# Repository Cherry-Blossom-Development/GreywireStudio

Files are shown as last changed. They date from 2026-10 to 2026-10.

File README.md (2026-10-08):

# GreywireStudio

GreywireStudio is a line of guitar effects pedals from Cherry Blossom Development. The first series, **Linework**, is a set of pedals that work on their own or together under a phone-connected control pedal. See `General Concept.docx` for the overall product concept. `Linework Control Specification.docx` defines the rules every Linework pedal follows: the MIDI loop connecting them to Switchyard, the shared message map, presets and firmware updates.

## Tools

All tools are free:

| Tool | Purpose |
|---|---|
| [KiCad](https://www.kicad.org/) | Schematic capture and PCB layout |
| [LTspice](https://www.analog.com/ltspice) | Circuit simulation (gain, clipping, tone response) |

## Layout

```
libraries/
  GreywireStudio.kicad_sym   # Shared KiCad symbols (e.g. 3PDT footswitch)
pedals/
  <pedal-name>/
    README.md   # Design notes, parts list, status
    *Product Document.docx  # Product definition
    kicad/      # KiCad project (schematic + PCB)
    sim/        # LTspice simulations (.asc)
```

## Pedals

| Pedal | Name | Type | Status |
|---|---|---|---|
| [Distortion](pedals/distortion/) | Flashover | Distortion / overdrive | Design |
| [Controller](pedals/controller/) | Switchyard | Control pedal (phone-connected) | Concept |

Product names are working names pending a trademark search.

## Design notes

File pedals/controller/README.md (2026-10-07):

# Controller Pedal (Switchyard)

The Linework series control pedal. A phone (iPhone or Android) plugs into it over USB-C, and two footswitches step up and down through pre-configured settings for all connected pedals. See `Switchyard Product Document.docx`.

## Status

Concept - product definition drafted, no circuit yet.

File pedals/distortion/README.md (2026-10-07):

# Distortion Pedal (Flashover)

The first GreywireStudio pedal: an analog distortion / overdrive in the Linework series, with gain, tone and level controls. It works on its own or controlled by the Switchyard control pedal. See `Flashover Product Document.docx`.

The design files still use the internal name GS1.

## Folders

- `kicad/` - KiCad project (schematic and PCB layout)
- `sim/` - LTspice simulations of the circuit

## Status

Design - circuit not yet started.

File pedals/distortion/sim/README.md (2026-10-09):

# Distortion - LTspice Simulations

## GS1.cir

Simulation of the GS1 schematic's effect-on signal path (footswitch engaged), using the same part names and values as `kicad/GS1/GS1.kicad_sch`.

**To run:** open `GS1.cir` in LTspice (File > Open, set the file type to "Netlists"), then press Run. Click a node or use Plot Settings > Add Traces to view `V(in)` (guitar) and `V(out)` (to the amp). Peak-to-peak levels are in View > SPICE Error Log.

**Settings** are the `.param` lines at the top of the file:

| Param | Meaning |
|---|---|
| `dist` | Distortion knob, 0 (min) to 1 (max) |
| `vol` | Volume knob, 0 to 1 |
| `amp` | Guitar signal level, volts peak (pickups give roughly 0.1-0.3) |
| `freq` | Guitar note frequency, Hz |

By default it steps the Distortion knob through 0, 0.5 and 1 and overlays the three results.

**Models:** LTspice has no LM741 model, so U1 is LTspice's "universal" op amp set to 741 specs. The 1N34A germanium diode model is a common community model, not a manufacturer one.

Generated output (`.raw`, `.log`, `.net`, `.db`, `.wav`) is ignored by git.

## Flashover simulations

The Flashover audio path: the GS1 gain stage scaled for 100k digital pots, switchable Soft (germanium) / Hard (silicon) clipping, a DS-1-style tone control, an output amplifier and a digital-pot Level control. See `Flashover Product Document.docx` one folder up.

| File | Purpose |
|---|---|
| `Flashover_circuit.inc` | The shared circuit. Not run directly; the files below include it |
| `Flashover_listen.cir` | Runs 2 seconds and writes `Flashover_out.wav` at the knob settings in the file |
| `Flashover_compare.cir` | Soft vs Hard at two Gain settings: output level, and checks that every digital pot terminal stays within 0-9V |
| `Flashover_tone.cir` | 20 Hz-20 kHz response at three Tone settings, 10k vs 20k Tone pot, and min/max Gain |

**Settings** (`.param` lines at the top of each run file): `dist`, `tone`, `level` (knobs, 0 to 1), `hard` (0 = Soft, 1 = Hard), `Rt` (Tone pot value), `Rw` (digital pot wiper resistance), `amp`, `freq`.

**Design changes from GS1, and why:**

- Digital pots only accept signals between 0V and 9V, so everything after the gain stage is centered on the 4.5V reference (VB) instead of ground. VB is buffered by an op-amp (U3) because the tone network and Level pot now return to it.
- Gain stage scaled by 10 for a 100k digital pot: R5 100k, R4 330 (instead of 470, to allow for the pot's wiper resistance: about 150 ohms at 9V according to the MCP45HV51 datasheet), C3 470n. Gain at 1 kHz: about 1.8x to 170x, the same as GS1.
- Output amplifier (U2) has a gain of 4 (+12 dB) to make up the tone network's loss, so the pedal can play louder than the bypassed guitar.

**Results (October 2026):**

- All digital pot terminals stay between about 3.4V and 5.5V, inside the 0-9V limit.
- Hard is about 8.5 dB louder than Soft at full Gain (7.7 dB at half Gain). Multiplying Level by 0.376 in Hard mode matches the loudness to within 0.1 dB, so the firmware can compensate automatically.
- A 10k Tone pot (available as a 9V digital pot) gives tone curves within about 3 dB of the DS-1's 20k, so 10k is used.
- At full Level and Gain, output is about +6 dB (Soft) and +14.5 dB (Hard) above the input guitar signal.

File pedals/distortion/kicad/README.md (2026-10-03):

# Distortion - KiCad Project

Create the KiCad project in this folder (File > New Project in KiCad).

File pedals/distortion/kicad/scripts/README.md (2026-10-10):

# Flashover generator scripts

These Python scripts generate the Flashover KiCad projects (`../Flashover` and `../Flashover_Controls`).

**Once anyone routes a board by hand in KiCad, the KiCad files become the master copy.** After that,
don't run `make_boards.sh`: it overwrites the `.kicad_pcb` files. The schematic generator
(`gen_flashover.py`) overwrites the schematics in the same way.

| Script | What it does | Run with |
|---|---|---|
| `gen_flashover.py` | Writes both schematics and their project files. Uses `kigen.py` and `kisym.py` | any Python 3 |
| `rules.py` | Design rules and net classes, written into the `.kicad_pro` files | (imported) |
| `netlists.sh` | Exports both netlists to `build/`, for the placement script | bash |
| `gen_pcb.py` | Places every part on both boards, in 1590BB pedal coordinates, and adds the board outline and copper planes | KiCad's Python |
| `fanout.py <project>` | Adds a short track and a via from each surface-mount pad down to its inner plane (GND on both boards, +5V on the control board) | KiCad's Python |
| `route.sh <project> [passes]` | Autoroutes with Freerouting (`route.py` and `dsnfix.py` handle the round trip), then adds ground pours | bash |
| `make_boards.sh [max passes]` | All of the board steps above, for both boards, followed by `drc.sh` | bash |
| `drc.sh` | Runs the design rule check, with schematic parity, on both boards and prints a summary | bash |
| `render.sh` | Renders both boards to `build/*_pcb.png` | bash |

- **Paths:** set in `paths.py` and `env.sh`. The KiCad 10 install paths are in `env.sh`, `gen_pcb.py` and `kisym.py`.
- **`build/`:** not committed. It holds netlists, router files and logs.
- **Freerouting:** download version 2.1.x (it runs on Java 21) from
  <https://github.com/freerouting/freerouting/releases> and save it as `build/freerouting.jar`.
- **Router quirks:**
  - Run headless, Freerouting ignores every pass limit tried (`-mp`, `--router.max_passes`, the settings file). It stops by itself after about 1,000 passes; `route.sh` also stops it after 90 minutes, and a stopped run saves nothing.
  - It can't connect pads at angles other than multiples of 90°, so the ring LEDs and U10 are placed square.
- **KiCad's Python quirk:** `pcbnew.SaveBoard` resets the project's design rules. Every script that
  saves a board calls `rules.apply_file` afterwards to put them back.

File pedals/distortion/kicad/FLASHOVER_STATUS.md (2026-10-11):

# Flashover circuit boards: where we are (updated 2026-10-10)

## In short

The schematic is finished and the parts are placed on two circuit boards. Wiring the boards together
("routing") is partly done: the control board is nearly finished, but the main board still needs
substantial work. Nothing is ready to order yet.

## What exists

Two KiCad projects, one per board:

| Folder | Board | What's on it |
|---|---|---|
| `Flashover/` | Main board | Audio circuit, microcontroller, digital pots, MIDI, bypass relay, and all five jacks along the top edge |
| `Flashover_Controls/` | Control board | The three knobs with their LED rings, the LED driver, the Soft/Hard button and the four panel LEDs |

- **Enclosure:** Hammond 1590BB, with the jacks mounted along the top edge.
- **Stacking:** the control board sits just under the top panel and plugs into the main board below it
  through a 20-pin connector (J8 on the control board into J7 on the main board).
- **Spacers:** two M3 screw holes on each board, in matching positions.
- **Panel layout (looking down at the pedal):**
  - Gain and Level knobs side by side at the top, with Tone below and centred.
  - Soft/Hard button at the lower left, with the Soft and Hard LEDs just above it.
  - On LED just above the footswitch; Link LED under the Level knob.
- **Schematic check:** passes with no errors on both projects.
- **Board check:** both boards match their schematics exactly.

## Where the routing stands

Both boards are 4-layer. The two inner layers are copper "planes" for ground (and +5V on the control
board), which keeps the audio quiet and cuts down the wiring.

| Board | Connections still missing | Wiring errors (shorts or too-close tracks) |
|---|---|---|
| Control board | **0 — fully routed** (last 7 by hand, 2026-10-10) | 0 |
| Main board | 50 | 0 |

- **Control board:** finished. The last 7 connections, all around the LED driver chip (U10), were
  routed by hand. Only cosmetic silkscreen (label) warnings remain, to be tidied before ordering.
  - L7 takes a long way round, past the right-hand knob and back. It works; tidy it later if wanted.
- **Main board:** the automatic router (Freerouting) gets most of it, but leaves gaps, mostly around
  the microcontroller's very fine pins.
- **Why route the main board by hand:** even a fully auto-routed main board would route the audio path
  poorly. My recommendation is to route it by hand in KiCad, starting with the audio path:
  input jack → gain → clipping → tone → output.

## Things to check against real parts before ordering

- **Jack spacing:** the five jacks along the top edge are very tight, with about 1 mm between bodies.
  A smaller 1/4" jack such as the Lumberg KLBM 3 would free about 10 mm (it needs a custom footprint).
- **Enclosure measurements:** I assumed walls about 3 mm thick and corner screw posts about 6.5 mm
  across. Both need checking against Hammond's 1590BB drawing.
- **Board stacking height:** the boards are about 11 mm apart, with the control board about 8 mm below
  the panel. This depends on the actual encoder and button heights.
- **Ring LEDs:** they sit below the panel, so each knob needs 11 small panel holes, or light pipes.
- **Encoders:** they use the Alps EC11E footprint. Confirm it matches the Bourns PEC11R drawing.
- **Audio capacitors:** C1–C5, C8, C9 and C12 must be C0G or film, not X7R.

## Done on 2026-10-10

- **Generator scripts saved** in `scripts/`, with a README explaining how to run them. Run from
  there, they reproduce the committed schematics exactly.
  - Once routing by hand starts, the KiCad files become the master copy. Don't re-run
    `make_boards.sh` after that: it overwrites the boards.
- **Product document updated** for the two-board design: a new "Circuit boards" section, and the
  sheet table now shows which board each sheet is on.
- **Tried to help the autorouter:** I turned the main board's In2 layer into a 3.3V plane, because
  half of the missing connections were 3.3V.
  - It made things worse, 70 missing connections instead of 50, including parts of the audio path.
    Losing In2 as a routing layer cost more than the plane saved.
  - I reverted it. The boards are as committed on 2026-10-09.
- **Conclusion:** the automatic router has gone as far as it usefully can on the main board.

## Next

**Hand-route the main board** in KiCad, together, the same way as the control board: one connection
at a time, with a check after each save. Start with the audio path:
input jack → gain → clipping → tone → output.

How to route by hand in KiCad (what worked on the control board):
- Use the **Design Rules Checker → Unconnected Items** list to find each gap.
- Set the grid to **0.1 mm** so the cursor can reach the fine-pitch pads.
- **Page Up** selects the top layer (F.Cu, red); **Page Down** the bottom (B.Cu, blue).
- Drawing a track:
  - **X**, then click the start, to begin.
  - Click to fix a corner.
  - **V**, then click, drops a via and changes layer.
  - **Esc** twice to stop.
- Surface-mount pads are only on the top layer, so a track arriving on the bottom needs a via
  just before the pad.
- If clicking opens the footprint chooser, a tool is on: press **Esc** until the arrow is selected.

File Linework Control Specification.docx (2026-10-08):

# Linework Control Specification

Shared rules for every pedal in the Greywire Linework series

Item | Detail
Version | 0.1 (draft)
Status | First proposal, to be refined as each pedal is designed
Applies to | Switchyard and every Linework effect pedal (Flashover is the first)
Related documents | General Concept.docx; Switchyard Product Document.docx; Flashover Product Document.docx

# Purpose

Every Linework pedal has to work with Switchyard, the app and every other Linework pedal, including pedals we haven’t designed yet. This document sets the rules they all follow: how they connect, how they’re controlled, what messages they understand, and how they’re updated.

The goal is that each new pedal can be designed on its own as long as it follows this specification. We don’t have to design every pedal before building the first one. Because every pedal can receive firmware updates, the specification can also be improved later and existing pedals updated to match.

# Design rules for every pedal

- Linking is always included. There are no unlinked versions of Linework pedals.
- No control holds a position that could disagree with a remote change. Knobs are endless (rotary encoders) with LED rings showing the real value. Switches are push buttons or momentary footswitches, with LEDs showing the real state.
- Settings survive power off. A pedal starts up exactly as it was left.
- Fail-safe bypass. The on/off switching uses a relay that connects input straight to output when the pedal has no power, so a dead pedal still passes the guitar signal.
- Presets. Every pedal stores 128 presets that can be recalled with a MIDI program change.
- Firmware updates through Switchyard, with a protected spare copy so a failed update can’t leave the pedal unusable.
- Power: standard 9V DC, 2.1 mm barrel, center negative. Each pedal lists its current draw.
- No batteries. Every pedal runs from a power supply cable; there is no battery compartment.

# Connections

## The MIDI loop

All Linework pedals connect to Switchyard in a single loop using standard MIDI over 3.5 mm TRS cables (“Type A” wiring). Every pedal has one MIDI in and one MIDI out jack.

- Switchyard MIDI out → pedal 1 MIDI in
- Pedal 1 MIDI out → pedal 2 MIDI in, and so on for each pedal
- Last pedal MIDI out → Switchyard MIDI in

Each pedal passes on everything it receives and adds its own messages (such as a knob turned by hand, or a reply to a question from Switchyard). This is called merging. It means:

- Switchyard needs only one output and one input, however many pedals are connected.
- Switchyard hears from every pedal, so the app always knows the current settings, which pedals are connected, and in what order.
- If a message doesn’t come back around the loop, Switchyard knows the loop is broken and the app can show where.

## Limits

- Up to 16 pedals, one per MIDI channel.
- Each pedal adds a very small delay as it passes messages on (well under 1 ms per message). A typical board of 6–8 pedals is no problem.
- MIDI cables carry control messages only, never audio or power.

## If a pedal loses power

A pedal with no power stops passing messages on. Because pedals have no batteries, this only happens if a power cable is knocked out or a supply fails, so no extra hardware is added for it. Instead:

- The sound keeps working. The unpowered pedal’s bypass relay passes the guitar signal straight through, so only that one effect drops out.
- Pedals before the break still receive Switchyard’s messages; only the pedals after it lose contact.
- Switchyard detects the break because its messages stop coming back around the loop, and the app shows which pedal to check.

# Setting up: identifying pedals and assigning channels

Channels are assigned automatically. The player only has to cable the loop.

- 1. Count: Switchyard sends a “position” message carrying the number 0 around the loop. Each pedal adds one, remembers the result as its position, and passes the new number on. The number that arrives back at Switchyard is the total number of pedals.
- 2. Identify: Switchyard sends the standard MIDI “identity request” around the loop. Each pedal replies with its model, firmware version, specification version, its position, and a unique serial number built into its microcontroller. From the positions, the app knows the order the pedals are cabled in.
- 3. Assign: Switchyard sends each pedal, addressed by serial number, the channel it should use. The pedal remembers its channel.
- 4. Confirm: the app shows the list of pedals in board order with their channels.

Manual fallback: every pedal has a setup mode, entered by holding its footswitch while plugging in power, where the channel can be chosen by hand and shown on the pedal’s LEDs. The exact controls depend on the pedal.

# Message map

## Control change messages

All pedals use the same control change numbers for the same kinds of controls, so Switchyard and the app can handle any pedal the same way.

Control change | Use | Values
20–27 | Knobs 1–8, in panel order (left to right, then top to bottom) | 0–127, fully down to fully up
52–59 | Optional fine adjustment for knobs 1–8 (standard MIDI pairing, for 16,384 steps instead of 128) | 0–127
80 | Effect on/off | 0–63 off, 64–127 on
81–87 | Mode switches 1–7 (such as Flashover’s Soft/Hard) | The option number: 0, 1, 2 and so on
Others | Reserved for future use

When a setting is changed by hand on a pedal, the pedal sends the same message out on its own channel, so Switchyard and the app stay in sync.

## Program change messages

- Program change 0–127 recalls preset 1–128 on that pedal’s channel.
- When a preset is recalled, the pedal sends its new settings out as control change messages so the app sees the result.

## System messages

Messages that aren’t about a pedal’s sound use MIDI “system exclusive” messages, which carry our own manufacturer ID. Proposed messages:

Message | Direction | Purpose
Position count | Switchyard → pedals → Switchyard | Each pedal learns its place in the loop; Switchyard learns how many pedals there are
Identity request / reply | Switchyard → pedals → Switchyard | Find out which pedals are connected (uses the standard MIDI identity request)
Assign channel | Switchyard → pedal | Set a pedal’s channel, addressed by its serial number
Report settings | Both ways | Ask a pedal for all its current settings; the pedal replies with them
Store preset | Switchyard → pedal | Write a preset slot, either with given values or with the pedal’s current settings
Read preset | Both ways | Read back a preset slot so the app can check it matches its copy
Firmware update | Both ways | Start, send data, verify and finish a firmware update (see below)

The detailed byte layout of each message will be written once the first prototype is working.

Manufacturer ID: MIDI reserves a temporary ID (7D) for development and non-commercial use, which we can use while prototyping. Before selling, we need our own ID from the MIDI Association, which has a small annual fee.

# Presets

- Every pedal stores 128 presets in its own memory, recalled by program change 0–127.
- Each pedal’s product document lists what a preset holds. For Flashover it’s Gain, Tone, Level, clipping mode and on/off.
- The app holds the master copy of every preset and writes them to the pedals through Switchyard. It can read them back to check they match.
- Proposal for setlists: when the app sends a setlist to Switchyard, it stores the settings each song part needs as presets in each pedal. Stepping to the next part then needs only one program change message per pedal. Switchyard can still send individual control change messages for live adjustments.

# Firmware updates

- Route: the app downloads firmware from the Greywire server, sends it to Switchyard over USB, and Switchyard sends it around the MIDI loop addressed to one pedal by serial number. The pedal confirms each part and reports when it’s finished.
- Protected: each pedal keeps two copies of its firmware. Updates go into the spare copy and are checked before the pedal switches over. A failed or interrupted update leaves the old version running.
- Recovery mode: each pedal has a button combination at power-up that starts a minimal recovery program waiting for a new update. Each product document lists its combination.
- During an update the pedal stays in bypass, so the guitar signal still passes.
- Speed: MIDI moves about 3 KB per second, so a typical update of 100–200 KB takes one to two minutes per pedal.
- Switchyard itself is updated directly over USB from the app.

# Timing

- A control change message takes about 1 ms to send.
- A preset change (one program change per pedal) takes about 1 ms per pedal, so a board of 8 pedals changes in under 10 ms.
- Sending every setting individually takes about 5 ms per pedal for a pedal like Flashover, so presets are the faster way to switch songs.

# Versioning

- Every pedal reports which version of this specification it follows, in its identity reply.
- New versions of the specification should only add things, never change the meaning of existing messages, so older pedals keep working.
- Pedals can be updated to newer versions with a firmware update.

# Open questions

- Do any pedals need more than 8 knobs or 7 mode switches?
- Is the fine-adjustment range (control change 52–59) needed for any pedal, or is 128 steps enough?
- Confirm the setlist proposal: presets in the pedals, recalled by program change.
- Should Switchyard offer a second loop for very large boards?

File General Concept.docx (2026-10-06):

What are we building?

Original idea

1) a multi-effects pedal
2) which connects to the internet
3) Therefore, we need a website

or maybe..

1) a small network of single effects pedals
2) which connect to each other
3) and maybe a master control pedal
4) also connecting to the internet
5) necessitating a website.

What features could we have

1) Pedal does what a pedal does (same as any other pedal)
2) pedal allows for remote control (either wirelessly or via a cable of some sort)
3) The remote control can adjust any pedal setting
4) The remote control is centralized and sequenced into easily changeable modes to accommodate any song. pre-set in order to play your songs, all controllable by a single tap floor-based device (a pedal)
5) The remote control can also integrate with external sound sensing devices (aka cellphones), which can determine overall band levels and adjust them live during a live, on-location performance
6) Somehow, the pedal also allows you to access a limited social network of other people who also have one of the devices (perhaps you need a specific MAC address or something to validate, not sure how this works actually)

Questions:

Question 1: If the pedals all do the same basic thing that other pedals do, why would anyone purchase them (especially if they cost more)

Answer: It’s all the other features you get from the remote-control stuff to the social network. This is added value

Question 2: What if the external control is annoying? Like, what if it turns your sound level down to the point where you can’t hear yourself?

Answer: We have a special monitoring device that goes along with the pedal, a little speaker that sits on your pedal board and can be adjusted independently

Question 3: Why would I want to use this social network?

A) The social network connects you to other musicians. This could be good, you could start a band or something
B) The social network also has built-in mixing and recording tools. The pedal can upload recordings directly to the network, which can be reviewed by others

Question 4: What about drummers?

Answer: Drummers suck… but for real though, we could also make drum tools, or also we could simply have a subscription model for people who want to be part of the network but don’t have a device available (like Saxophone players, fuck those guys)

Question 5: So, does the pedal also record you?

Answer: Uh, yeah, maybe? I just typed that, so I guess we should look into it

# Connectivity: How Does the Pedal Reach the Internet?

Both ideas (Wi-Fi through the phone, or Bluetooth to the phone) work, and we don’t have to pick one. The usual chip for this, the ESP32, has Wi-Fi and Bluetooth built in and costs a few dollars. The bigger cost decisions are elsewhere: certification, the phone app, and how the pedals talk to each other.

## Option 1: Wi-Fi through the phone’s hotspot

Doable. The command pedal joins the phone’s hotspot like a laptop would. Some catches:

- Users have to turn on their hotspot every time. On iPhone it’s fiddly, and some phone plans charge for it or cap it.
- The same Wi-Fi radio can join home or venue Wi-Fi directly, so the hotspot should be a fallback, not the main path.
- Big advantage: we might not need a phone app at all. The pedal can serve a setup page, then talk straight to the website. The Breakroom backend already does this kind of thing.
- Wi-Fi is fast enough to upload recordings.

## Option 2: Bluetooth (BLE) to a phone app

Doable, and it’s how most commercial “smart” pedals and amps work (Boss, Line 6, Positive Grid Spark). The pedal talks to an app, and the app relays to the internet.

- It needs a native phone app. iPhone browsers can’t talk to Bluetooth devices, so that means an Android app (Kotlin) plus an iOS app.
- Connecting is easy for users: pair once and it reconnects automatically.
- Lag is low, around 10–30 ms, which is fine for switching presets.
- It’s slow for big files. A 3-minute recording is about 15–30 MB, and BLE would take minutes to move it.
- This concept needs apps anyway. The musician needs an app to control the pedal, and the band-level feature needs an app for the separate person who measures the band’s mix (see Band-Level Monitoring at the end of this document). That tilts things toward Bluetooth.

## Recommendation: both, on one chip

Put an ESP32-S3 in the command pedal only:

- Bluetooth to the phone app for control and presets, and to receive level adjustments from the band-level feature
- Wi-Fi for uploading recordings, firmware updates and the social network when a network is available

Two rules:

- Never send a footswitch press over the internet. Song-mode changes have to work locally, in a basement with no signal.
- Connect the effect pedals to the command pedal with a cable, not wirelessly. A crowded stage is full of 2.4 GHz interference, and a missed preset change mid-song is a dealbreaker. MIDI over a TRS cable is the industry standard and cheap. A cable also keeps radio noise out of each pedal’s analog audio.

## Other options

Option | Verdict
USB-C to phone or computer | Worth adding. It’s cheap, very reliable and great for recording. Could be a second path rather than the main one.
ESP-NOW (ESP32-to-ESP32 wireless, no router) | Works for pedal-to-pedal links, but has the same stage-reliability worry as above.
Cellular (LTE-M or 4G module) | Works anywhere, but costs $10–30 per unit, plus a $2–10/month data plan and expensive carrier certification. Not worth it at this stage.
Ethernet | Nobody runs network cable to a pedalboard.

## What this means for the GS1 circuit

- Remote control of knobs: GS1 uses ordinary mechanical knobs, which a chip can’t turn. We’d need digital potentiometers that run on the full 9V (e.g. Microchip MCP41HVxx, about $1.50–2.50 each). Another route is doing the effect digitally in software.
- Recording: the ESP32’s built-in audio input is too poor for this. We’d need an audio converter chip (about $2–5) and an SD card slot (about $1).

## Rough costs

Parts per pedal (at small production runs)

Item | Cost
ESP32-S3 module (Wi-Fi and Bluetooth, pre-certified) | $3–6
Power converter from 9V to 3.3V* | $1–3
MIDI jacks and parts for the cable link | $1–2
Small chip in each effect pedal to receive commands | $1–3
9V digital pots, per knob | $1.50–2.50
Audio converter and SD slot (if recording) | $3–6
Extra cost, command pedal | about $10–20
Extra cost, each effect pedal | about $3–8

*Wi-Fi draws bursts of up to about 350 mA. A simple regulator from 9V would get too hot, so a more efficient switching converter is needed.

Retail price usually ends up about 3–4× the parts cost.

One-time and ongoing costs

Item | Cost
Prototyping boards (ESP32-S3 DevKit is about $15) | $50–150
FCC testing (US), using a pre-certified module | about $2k–5k
CE/RED testing (only if selling in the EU) | about $3k–10k
Bluetooth SIG listing fee (required to sell anything with Bluetooth) | about $5k–10k; check the current price
Apple developer account | $99 per year
Google Play account | $25 once
Server | Already running on EC2

The Wi-Fi Alliance logo program is optional. The Bluetooth fee and FCC testing are the big unavoidable costs, and they’re one-time costs per product. Using a pre-certified radio module, rather than designing our own radio, is what keeps FCC testing in the low thousands instead of tens of thousands. The certification prices are estimates, so get quotes before budgeting around them.

## Next step

Finish GS1 as a plain analog pedal. Separately, buy an ESP32-S3 dev board (about $15) and a 9V digital pot, and prototype changing GS1’s Distortion knob from a phone over Bluetooth. That one experiment tests the core idea for about $20.

# Certification Without Wi-Fi or Bluetooth

Mostly not needed, at least in the US, as long as the pedals stay fully analog.

## United States (FCC)

A fully analog pedal like GS1 needs no FCC testing or paperwork. FCC rules cover devices that transmit radio on purpose, like Wi-Fi and Bluetooth. They also cover “digital devices,” meaning anything with a clock signal running above 9 kHz. An op-amp, diodes and knobs are neither, which is why most small builders who make analog pedals sell them in the US without testing.

We still can’t cause harmful interference, but a properly built analog pedal won’t.

This changes as soon as we add a chip with a clock. Examples are a microcontroller for preset switching, relay bypass or tap tempo, or a digital delay chip like the PT2399. The pedal then counts as a Class B digital device. That means a self-declaration, but in practice it means paying a lab to test emissions, typically about $1k–3k per product. It’s still much cheaper than the wireless route, and there’s no FCC filing fee or ID number.

## Fees that go away entirely

- Bluetooth SIG fee: only applies to Bluetooth products.
- Apple and Google developer accounts: no app needed.

## Selling in Europe or the UK

These rules apply even to analog pedals:

- CE marking (UKCA in the UK). The EMC rules cover any electronic device. Self-declaration is allowed without a mandatory lab test, but it requires a technical file. Many small makers pay for a test anyway to be safe, about $1k–3k.
- RoHS: parts and solder must be lead-free. That’s easy if we plan for it from the start.
- WEEE registration: a recycling registration in each country we sell to. It’s small but annoying paperwork, especially in Germany.

Selling only in the US to start avoids all of this.

## Smaller things that still apply

- Power supply: don’t make our own. If one goes in the box, buy one that’s already safety-certified (UL/ETL). Most pedal makers don’t include one at all, and players already own one.
- California Prop 65: standard pedal jacks are made of brass that contains a little lead. Many pedal makers add a Prop 65 warning label. It costs nothing, but it’s worth knowing about.
- Product liability insurance: not required, but common once sales get going. Typically a few hundred to a couple thousand dollars a year for a small business.

So plain analog pedals sold in the US have essentially no certification cost. That makes GS1 a good first product to sell while the connected version is worked out.

This is a general picture, not legal advice. Before selling in Europe, a compliance lab will give a free quote and confirm exactly what applies.

# Alternative: Plug the Pedal Into the Phone (USB-C)

Instead of building Wi-Fi or Bluetooth into the pedal, it could plug into the player’s phone with a USB-C cable and use the phone’s connection. This works, and it’s cheaper. Most of the savings are one-time fees, though; the per-pedal savings are only a few dollars. It’s also the better option for recording and the worse one on stage.

## How it would work

The pedal gets a USB-C port and a small microcontroller. It plugs into the phone, and a phone app relays everything to the internet.

The key design trick: make the pedal a standard USB audio and MIDI device, the same kind as the plug-in guitar interfaces sold for phones. iPhones (USB-C models, iPhone 15 and later) and Android phones support these with no special drivers. Control messages go over MIDI, and recordings stream as full-quality audio.

Older Lightning iPhones would need Apple’s $29–39 camera adapter. Making a pedal that talks to iPhones any other way requires Apple’s MFi licensing program, which is slow and restrictive, so stick to the standard device types.

## What it saves

Cost | Wireless (ESP32) | USB to phone
Bluetooth SIG fee | $5k–10k | $0
FCC testing | $2k–5k (radio product) | $1k–3k (self-declared digital-device test)
USB vendor ID | — | $0 with a free product ID from the chip maker (Raspberry Pi and others offer these); $6k to buy our own
App development (iOS + Android) | Needed | Still needed
Parts per pedal (control only) | about $10–20 | about $3–6
Parts per pedal (with recording) | plus audio chip and SD card | about $6–15; no SD card needed, the phone stores it

The microcontroller can be very cheap, e.g. a Raspberry Pi RP2040 at about $1, which has USB built in. We also skip the switching power converter, because there’s no Wi-Fi drawing big bursts of current. A Class B digital device still needs that FCC test, though, so we save on the Bluetooth fee but not all certification.

Rough total savings: about $5k–12k up front and about $5–10 per pedal.

## The trade-offs

Better:

- Recording is much better. Full-quality audio streams straight into the phone app, with no slow Bluetooth transfers and no SD card. It also works with a laptop recording program, which is a nice extra.
- No radio interference anywhere near the analog audio.
- Simpler firmware and fewer connection problems.

Worse:

- The phone has to sit on the pedalboard, plugged in, for the whole gig. Cables get kicked, notifications pop up, and the phone’s only port is in use, so it can’t charge without a hub. That’s awkward for live use.
- Hum risk: the phone (especially while charging) plus the amp can create a ground loop. We may need a USB isolator chip, about $5–8 per pedal, which eats into the savings.
- The phone can’t really power the pedal, so it still needs its normal 9V supply.

## How it fits the concept

A sensible staged plan:

- Version 1: USB only. The pedal works standalone on stage, with presets and song modes stored in the pedal itself. Players plug it into a phone or computer at home to edit presets, record, upload to the social network and update firmware. This is the cheapest way to launch the internet-connected idea.
- Version 2: add wireless once sales justify the Bluetooth and certification costs, so players can control the pedal without their phone plugged into the pedalboard. The band-level feature doesn’t need this; it works through the musician’s phone in version 1.

A first prototype costs about the same as before: an RP2040 board (about $5) and a 9V digital pot, controlled from an Android phone over USB MIDI.

# Fully Integrated Mobile Device

The original plan was analog effect circuits in each pedal, plus a small computer (like an Arduino) in the pedal to receive commands and change settings such as volume. With the pedal plugged into a phone, the phone can take over much of that work, and even produce some of the effects itself in software.

The chosen direction is a hybrid. Effects where delay would be a problem stay as real analog circuits built into the pedal. Effects that are naturally digital run as software in the phone app. This section explains how that works, why it solves the latency problem, and what it costs.

## The short answer

- Analog in the pedal: drive effects (distortion, overdrive, fuzz, boost), dynamics (compression, noise gate), filters and wah, and modulation that changes the whole signal (phaser, flanger, tremolo, vibrato). These need an instant response, and they’re traditionally analog anyway.
- Digital in the phone: reverb, delay, chorus and pitch shifting, plus tools like a looper and tuner. These are traditionally digital, and they tolerate a small delay if the design is done right.
- The trick that makes it work: the clean (“dry”) signal never goes through the phone. The phone only adds the effect sound (the “wet” signal) on top, so the phone’s delay doesn’t affect the feel of playing.
- The pedal still needs a small computer. Since the analog effects are in the pedal and the phone needs to change their settings, the pedal needs a small, cheap microcontroller (about $1–4) to receive commands and set the knobs.
- Certification: one product with a USB chip needs one FCC self-declared test (about $1k–3k). Building several analog effects into one box instead of separate pedals means one test, not several.
- Bonus: if the phone dies on stage, the analog effects keep working. Only the reverb and delay drop out.

## Why a phone can’t turn a knob directly

A phone’s USB-C port carries only digital data, plus 5V power. When the phone and pedal are connected, the phone is in charge (the USB “host”) and the pedal is a “device.” The phone sends and requests small packets of numbers, and something on the pedal has to receive those packets and turn them into an action. The phone can’t put an arbitrary analog voltage on a pin to move a volume setting.

One possible shortcut is a dead end. Some Android phones support passing plain analog audio through the USB-C port (the mode used by cheap USB-C headphone dongles). iPhones don’t, and many Android phones don’t either, so we can’t rely on it.

Since the hybrid design keeps analog circuits in the pedal, something in the pedal has to receive the phone’s commands and adjust those circuits. That’s the microcontroller’s job.

## Options considered

| A. Phone does everything | B. Analog pedal, no-code USB chip | C. Analog pedal, small microcontroller | D. Hybrid (chosen)
What’s in the pedal | Guitar in/out circuits, USB audio chip, footswitches | Analog effects, digital pots, a USB bridge chip | Analog effects, digital pots, a microcontroller | Analog effects, digital pots, a microcontroller, a USB audio path to the phone
Where the sound is made | All in the phone | All in the pedal | All in the pedal | Drive, dynamics, filters, wah and whole-signal modulation in the pedal; reverb, delay, chorus, pitch, looper and tuner in the phone
Works with iPhone? | Yes | No; iPhone apps can’t talk to custom USB devices | Yes | Yes
Latency risk | High, every note goes through the phone | None | None | Low; only the wet signal goes through the phone
If the phone fails | Silence (needs a bypass relay) | Pedal keeps working | Pedal keeps working | Analog effects keep working; digital effects drop out

Option A had the cheapest hardware, but every note would pass through the phone, and Android phones vary too much in speed for that to be reliable. Option D keeps the parts of A that work well and avoids its biggest risk.

## Which effects go where

Our general split matches how the industry already works. The rule of thumb: if an effect needs an instant response, or it changes the whole signal so there’s no dry signal to keep instant, it goes in the pedal. If it adds something on top of the dry signal, it can go in the phone.

The Status column shows which placements we’ve decided and which are proposed and still to be reviewed one at a time. This is the full catalog. Which effects go into the first product is a separate decision; not every effect fits in one pedal.

Analog, in the pedal

Effect | Why | Status
Compression | Has to react instantly to how hard the string is hit | Decided
Noise gate | Must cut hum and hiss instantly between notes. A simple analog circuit | Proposed
Clean boost | Just a gain stage with a handful of parts | Proposed
Overdrive, distortion, fuzz | The core of the player’s tone; GS1 becomes the first of these | Decided
Octave fuzz, analog octave down | Classic analog circuits that follow the playing instantly. They complement the phone’s pitch shifting rather than replacing it | Proposed
Wah | The player sweeps it with their foot in real time, so any delay would be felt immediately | Decided
Volume pedal | Also controlled by the foot in real time; can share the expression pedal jack with the wah | Proposed
Filters (EQ, envelope filter / auto-wah) | Cheap and classic as analog circuits; feel matters | Decided
Phaser | Blends the signal with a phase-shifted copy of itself, which needs perfect timing. Also a cheap, classic analog circuit | Decided
Uni-Vibe style | A 1960s cousin of the phaser; same reasons | Proposed
Flanger | Needs very short delays (about 1–10 ms), shorter than the phone can manage. Analog flangers use a “bucket brigade” delay chip | Decided
Vibrato | Bends the pitch of the whole signal, so there’s no dry signal to keep instant. Uses the same bucket brigade chip as the flanger | Decided
Tremolo | Changes the volume of the whole signal. Simple and cheap as an analog circuit | Decided
Ring modulator | Changes the whole signal; a classic analog circuit | Proposed

Digital, in the phone

Effect | Why | Status
Reverb | Reverb naturally starts a little after the note, so a small delay is inaudible | Decided
Delay / echo | The app subtracts the phone’s delay from the echo time, so echoes land exactly on time | Decided
Chorus | Mixes in a copy delayed by roughly 10–25 ms anyway, so it works if the phone’s delay is shorter than that. Fine on iPhone; slower Android phones may struggle. Could move to analog later using the flanger’s delay chip | Proposed
Harmonizer (adds a pitched note alongside the original) | The original note stays on the instant dry path | Decided
Whammy / polyphonic pitch shift (replaces the original note) | There’s no dry signal to hide behind, so the delay is audible on slow phones. Best treated as an iPhone or fast-phone feature | Decided
Looper | Records and plays back loops. The app knows the phone’s delay, so it can line loops up exactly, and the phone has plenty of storage | Proposed
Tuner | Only needs to listen, so delay doesn’t matter. The pedal mutes its output while tuning | Proposed
Amp and speaker cabinet simulation | Changes the whole signal, so the phone’s delay matters when playing live. Most useful for headphone practice and recording straight into the phone | Proposed

## How the signal flows

1. Guitar input: a buffer circuit prepares the guitar signal.

2. Analog chain, in the usual order: compressor, then wah and filters, then octave and drive (fuzz, overdrive, distortion, boost) with the noise gate after them, then modulation (phaser, Uni-Vibe, flanger, vibrato, ring modulator) with tremolo last. Each can be switched in or out, and their knob settings are controlled by the microcontroller. Letting players reorder the analog effects is possible later, but needs extra switching hardware.

3. Split: the signal splits in two. The dry path goes straight to the output mixer with no delay at all. A copy goes through the USB audio chip to the phone.

4. Phone: the app produces only the effect sound (reverb tail, echoes, chorus voice and so on) and sends it back over the same cable.

5. Output mixer: a simple analog circuit blends the dry signal with the returning effect sound and sends it to the amp.

This is the same idea as an “effects loop” or the send-and-return setup on a mixing desk. It also matches the standard pedal order: dynamics and drive first, then modulation, delay and reverb at the end.

Measuring the phone’s delay automatically: the app can play a short click out to the pedal and time how long it takes to come back. It can then compensate its delay times for that phone. Players never have to think about it.

## How the phone “turns a knob”

The two kinds of effects handle knobs differently:

- Digital effects (in the phone): each setting is just a number in the app, applied in software. Nothing physical has to change, and the phone screen shows the current settings.
- Analog effects (in the pedal): the knobs in the analog circuits are replaced by digital potentiometers. These are chips that act as variable resistors, with the value set by the microcontroller. We need versions rated for the full 9V (e.g. Microchip’s MCP41HV/MCP44HV family). Single ones cost about $1.50–2.50, and quad chips bring the cost down to well under $1 per knob.

Other ways to move an analog knob were considered:

Approach | How it works | Cost per knob | Verdict
Motorized pot | A small motor physically turns a real knob, like the faders on big mixing desks | $10–20, plus a motor driver | Too expensive and bulky
Digital pot with endless encoder | The physical knob is an “endless” encoder that the microcontroller reads, often with a ring of LEDs to show the setting. Turning it or changing the setting from the phone both just change the digital pot | $1–2.50 for the pot, plus $1–3 for the encoder and LEDs | Best if players want physical knobs
Digital pot, no physical knob | All adjustments are made in the app; the pedal shows nothing | $1–2.50 | Cheapest; fine for song presets
Plain mechanical knob | A normal knob | Under $1 | Can’t be remote-controlled; its pointer would be wrong after the app changes a setting

Song modes work across both halves. A song preset is a saved set of numbers: digital pot values and on/off states for the analog effects, plus settings for the phone’s effects. Pressing a footswitch loads the next preset. The app sends the analog settings to the microcontroller and applies the digital ones itself, and the whole sound changes at once.

Switching an analog effect in or out is done by small electronic switches or relays controlled by the microcontroller. The circuit should mute and unmute gently during switching to avoid pops.

Some effects need special handling:

- Wah: the player controls wah with a rocking foot pedal (a treadle), not a knob the phone sets. The simplest approach is an expression pedal jack on the main pedal. The player plugs in a standard expression pedal, and its position drives the wah directly through a normal analog pot, so the sweep is perfectly smooth. The microcontroller only turns the wah on and off. Driving the sweep through a digital pot is possible, but its small steps can be audible as a faint “zipper” noise during fast sweeps. A built-in treadle is possible too, but it makes the pedal much bigger.
- Volume pedal: works the same way as the wah, through the expression pedal jack. A second jack would let players use both at once.
- Modulation speed: the app knows each song’s tempo, so it can set the speed of the tremolo, phaser, flanger or vibrato to match the beat as part of the song preset. That’s a nice feature that standalone analog pedals can’t easily offer.
- Flanger and vibrato use a “bucket brigade” delay chip, which runs on a clock signal. That’s fine for certification, since the pedal is already a digital device because of its USB chip.

## The communication protocol

USB defines standard “device classes,” which are agreed formats for common kinds of devices. A device that follows one is called class-compliant, and phones support the common ones with no driver or special app permission. Sticking to these classes is what lets the pedal work on both iPhone and Android, and lets us avoid Apple’s MFi licensing program.

The pedal shows up as two standard devices at once over one cable:

USB class | What we’d use it for | Notes
USB Audio Class | Sending the guitar signal to the phone, and the phone’s effect sound back | The phone sees the pedal as a sound card. Uses only a small fraction of the cable’s capacity
USB MIDI | Phone to pedal: analog knob values and effect on/off. Pedal to phone: footswitch presses and encoder turns | Same message format musicians have used since the 1980s. Works on iPhone and Android

Example: setting the distortion level from the phone. If we assign controller number 20 to the distortion knob, setting it to 100 out of 127 is three numbers:

- B0 means “control change on channel 1”
- 14 is the controller number (20 in hexadecimal)
- 64 is the value (100 in hexadecimal)

Over USB, those three bytes travel in a 4-byte packet (0B B0 14 64). The microcontroller receives it and writes the matching value to the distortion’s digital pot, and the sound changes. A footswitch press going the other way would be a similar message, for example a “program change” meaning “switch to preset 5.” MIDI values only go up to 127, which is coarse for a smooth sweep. Pairing two messages gives 16,384 steps when we need finer control.

On the phone side, the app uses the standard audio and MIDI frameworks: Core Audio and Core MIDI on iPhone, and AAudio (through Google’s Oboe library) and android.media.midi on Android.

On the pedal side, the microcontroller runs free open-source USB code (TinyUSB) that already supports devices that are both an audio device and a MIDI device. Its own program then reads the footswitches, sets the digital pots and switches, and remembers the current settings.

## Latency in the hybrid design

Round-trip latency is the delay for a signal to go into the phone and come back. As a rough guide, under about 10 ms feels instant, 10–20 ms is noticeable to many players, and over about 30 ms feels broken.

In the hybrid design those numbers apply only to the effect sound, not the notes the player hears directly. Because the dry signal is instant:

- Reverb and delay are unaffected in practice, even on slower Android phones.
- Chorus and harmonizer work well on iPhones and most recent Android phones.
- Only effects without a dry signal (whammy-style pitch shifting) are sensitive to slow phones.

That makes Android support much more realistic than it was in the phone-does-everything design.

The USB chip in the pedal also adds a little delay. For prototyping, the RP2040 microcontroller can handle USB audio itself with an add-on audio converter chip. For the production version, a chip designed specifically for USB audio, such as XMOS (about $5–8), gives the lowest delay.

## What happens if the phone fails on stage

This is a big advantage of the hybrid design:

- Phone disconnects or crashes: the analog effects keep running at their current settings, and the footswitches still turn them on and off, because the microcontroller handles that locally. Only reverb, delay and the other phone effects drop out.
- Pedal loses power: a relay that defaults to connecting the input straight to the output passes the clean guitar signal. This costs a few dollars and needs no programming.
- The app should still turn on Do Not Disturb or a “gig mode” to block calls and notifications.

## Power

- The pedal needs a normal 9V pedal supply. Analog effects need more power and voltage than a phone’s USB port can comfortably give, and running from the phone would drain its battery quickly.
- Optionally, the pedal could charge the phone from that same supply while connected. That needs a USB-C power controller chip (roughly $2–5) and makes the USB design a bit more complex, but it solves the problem of the phone’s only port being in use for the whole gig.

## Costs

Parts per pedal, example with six analog effects (compressor, wah, filter, drive, phaser, tremolo) and about 15 knobs, at small production runs

Item | Cost
Five analog effect circuits: compressor, filter, drive, phaser, tremolo (op-amps, transistors, diodes, resistors, capacitors) | $20–45
Wah circuit (including its inductor) and expression pedal jack | $4–8
Digital pots for about 15 knobs (quad chips) | $12–30
Electronic switching for effects on/off, plus fail-safe bypass relay | $4–10
Microcontroller with memory and crystal | $2–4
Audio converter chip (prototype) or USB audio chip (production) | $2–8
Input buffer and dry/wet output mixer | $1–3
USB-C connector and protection; 9V input and voltage regulators | $3–6
Footswitches (6–8) | $8–24
Endless encoders and LED rings (optional) | $8–25
Larger enclosure, jacks, circuit board | $20–40
Total per pedal | about $85–205

Retail is usually 3–4× the parts cost, putting this roughly in the price range of mid- to upper-range multi-effects units. The difference is that it includes six real analog effects plus effects that can be added through software. A cheaper model with fewer analog effects (for example compressor, drive and tremolo) is an easy variation.

Each additional analog effect from the catalog adds roughly $3–10 in parts plus its digital pots. Flanger and vibrato are at the high end, because the bucket brigade delay chip and its clock chip add about $4–8 each.

One-time costs

Item | Cost
FCC test (one product) | about $1k–3k
USB vendor ID | $0 with a free product ID from the chip maker (Raspberry Pi offers these for RP2040); $6k to buy our own
Bluetooth fee, Apple MFi license | $0
Pedal programming | Moderate; open-source USB code covers the hard parts
App development (iOS + Android) | The biggest cost; see below

Where the work is: the app has to produce reverb, delay, chorus and pitch effects reliably with low delay on both iPhone and Android. That’s months of specialized software work. It’s easier than the phone-does-everything design, though, because the hardest-to-model effects (distortion and fuzz) stay as real circuits.

## What changes about the product

- GS1 carries straight over. The distortion we’re already designing becomes the drive section of the hybrid pedal, with its knobs swapped for digital pots.
- The pedal network becomes part hardware, part software. Analog effects are built into the pedal; digital effects are app modules that can be sold as in-app purchases or included with a subscription, and added without manufacturing anything. Later, separate analog pedals could join the network over a MIDI cable from the main pedal.
- The social network gets easier. The app already receives the guitar audio, so recording and uploading is built in.
- It answers players who want analog tone. The tone-defining effects are genuine analog circuits, which sets this apart from phone apps that model everything in software.
- The phone must stay on the pedalboard, so the cable and notification concerns from the USB section still apply.

## Next step

Two cheap experiments test the two halves:

- Analog control: build GS1 on a breadboard as planned. Then replace the Distortion knob with a 9V digital pot controlled by an RP2040 board (about $5) and send it MIDI from a phone. This proves the phone-to-knob path.
- Digital effects: buy a small mixer with a built-in USB audio interface (about $40–60). Send the guitar to the phone, have a simple test app return only a reverb or echo, and blend it with the dry guitar in the mixer. This proves the dry/wet idea and lets us hear how phone delay affects each effect, on real iPhone and Android phones.

Together that’s under $100, before designing the full board.

# Band-Level Monitoring

The band-level feature measures the overall sound of the band in the room and adjusts each musician’s level live during a performance. This is done by a separate person, not the musician playing through the pedal. For example, a sound person, a band manager or a friend in the audience. They use either a separate monitoring app or a monitoring mode in the same app, on their own phone.

## How it works

- The monitoring phone is out in the room, where the audience hears the band, not tied to anyone’s pedalboard. Its microphone measures the overall mix.
- The monitoring app works out adjustments, such as “guitar 2 down a little.” These can be automatic, or suggestions the monitoring person approves.
- Adjustments travel to each musician’s phone, and that phone’s app passes them to the pedal. With the wired USB design, the pedal’s phone is already connected, so no wireless hardware is needed in the pedal for this feature.
- The pedal applies the change with a digital pot on its master output level. Players can still hear themselves through the small monitor speaker on their pedalboard, which they adjust independently (see Question 2).

## How the phones talk to each other

Route | How it works | Trade-offs
Through the internet (our server) | Both phones are online; the monitoring app sends adjustments to our server, which forwards them to each musician’s app | Simplest, and works at any distance. A delay of a fraction of a second is fine for level changes. Needs mobile signal or Wi-Fi at the venue
Local Wi-Fi network | Both phones join the same Wi-Fi network and talk directly | Works without internet access, but needs a network at the venue
Phone-to-phone Bluetooth | The monitoring phone connects directly to each musician’s phone | No network needed, but range from the room to the stage can be unreliable, especially in a crowd

A sensible approach is the internet route by default, with a local fallback for venues without signal.

Effect on the earlier sections: the guitarist’s phone sitting on the pedalboard doesn’t limit this feature, since the measuring is done elsewhere. That means wired USB to the phone and the hybrid design both fully support band-level monitoring.

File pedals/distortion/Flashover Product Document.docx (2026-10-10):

# Flashover

Distortion / Overdrive Pedal — Greywire Linework Series

Item | Detail
Product | Flashover distortion / overdrive pedal
Series | Linework (Greywire Studio)
Status | Draft — schematic drawn and parts placed on two circuit boards (version 0.1); board wiring in progress; breadboard prototype next
Design files | pedals/distortion/ — KiCad projects for the main board (kicad/Flashover) and the control board (kicad/Flashover_Controls), the scripts that generate them (kicad/scripts), the original GS1 design (kicad/GS1) and LTspice simulations (sim/Flashover_*.cir)
Related documents | General Concept.docx; Linework Control Specification.docx; Switchyard Product Document.docx

# Overview

Flashover is an analog distortion and overdrive pedal. Its sound is based on the classic MXR Distortion+ circuit (a single op-amp gain stage with clipping diodes), with a third knob added for tone, similar to the Boss DS-1.

It works two ways:

- On its own, as a normal distortion pedal: guitar in, amp out, three knobs, a Soft/Hard clipping button and an on/off footswitch.
- Linked to Switchyard, the Linework control pedal. Switchyard can turn Flashover on and off, set all three knobs, choose the clipping mode and recall stored presets automatically for each part of each song.

The gain range covers light overdrive at low settings through to full distortion at high settings, which is why it’s described as both.

Linking is part of every Flashover. There is no unlinked version: the connection to Switchyard, the app and the social network is what sets Linework apart from other pedals on the market.

# Name

A flashover is what happens when voltage gets so high that electricity jumps across the gap it’s supposed to stay behind. It’s a good picture of a signal being pushed past its limits, and it fits the wire theme of Greywire Studio and the Linework series.

“GS1” can’t be used as a product name. Boss sells a guitar called the EURUS GS-1, and GS1 is also the global barcode standards organization. GS1 stays as the internal name of the existing design files for now.

A web search in October 2026 found no pedal named Flashover. That isn’t a trademark clearance, so a proper trademark search is still needed. Tripwire is a backup name that also came back clear.

# Controls

Control | What it does
Gain | How hard the signal is driven. Low settings give a light overdrive, high settings give full distortion
Tone | Darker to brighter. Like the DS-1, it blends between a filter that keeps the bass and one that keeps the treble
Level | Output volume
Soft / Hard button | A push button that switches the clipping diodes between Soft (germanium) and Hard (silicon). Two LEDs labelled Soft and Hard show which is active
Footswitch | Turns the effect on and off
Status LEDs | An On LED by the footswitch shows when the effect is on. A Link LED shows when the pedal is linked to Switchyard

Gain, Tone and Level are endless knobs with LED rings, described under “How the knobs work” below. All the controls follow the Linework rule that a physical control never holds a position that could disagree with a remote change.

# Sound and circuit

- Gain stage and clipping: taken from the existing GS1 design, a Distortion+-style circuit with one op-amp gain stage and a pair of clipping diodes (now switchable; see Soft / Hard clipping below). It’s simulated in LTspice and drawn in the Flashover KiCad schematic.
- Tone control (new): a DS-1-style tone network after the clipping diodes: a low-pass filter (6.8k and 100n, about 234 Hz) and a high-pass filter (22n and 6.8k, about 1.06 kHz), blended by a 10k Tone pot.
- Output amplifier (new): after the tone network, with a gain of 4 (+12 dB). It makes up the volume the tone network loses, so the pedal can play louder than the bypassed guitar, and keeps the Level pot from loading the tone network.
- Centered on 4.5V: digital pots only accept signals between 0V and 9V, so everything after the gain stage is centered on the pedal’s 4.5V reference instead of ground. A small buffer amplifier keeps that reference steady.
- Op-amps: an LM741 for the gain stage, as in GS1, and a TL072 dual op-amp for the output amplifier and the 4.5V buffer.

## Soft / Hard clipping

The clipping diodes are what turn the boosted signal into distortion. The two settings use different diode types:

Setting | Diodes | Sound
Soft | Germanium (1N34A, as in the current GS1 design) | Start clipping at a low voltage and round off the peaks gradually. Smoother, warmer, more like overdrive
Hard | Silicon (e.g. 1N4148, as used in the DS-1) | Clip more abruptly, giving a sharper edge and more of a classic distortion sound

- How it switches: both pairs of diodes are on the board. Each press of the button switches to the other mode. A small signal relay (Omron G6K-2), switched by the microcontroller, connects one pair or the other, and the matching LED lights. With the relay off the Soft pair is connected, so the pedal is in Soft until the microcontroller restores the saved mode at power-up. Switchyard can set the mode the same way, and the LEDs always show the real setting.
- Volume difference: silicon diodes let the signal get louder before clipping, so Hard mode is about 8.5 dB louder at full Gain. The microcontroller compensates automatically by reducing the Level setting to about 38% of its value in Hard mode, which the simulation shows matches the loudness to within 0.1 dB.

# How the knobs work

Gain, Tone and Level use endless knobs with LED rings. Each knob turns freely in both directions with no end stops, and a ring of small LEDs around it shows the actual setting. This means the knobs are always accurate, whether a setting was changed by hand or by Switchyard.

- Turning a knob by hand: the microcontroller reads the knob (a part called a rotary encoder) and adjusts the setting up or down. The LED ring follows, and the pedal reports the change back to Switchyard so the app always knows the current sound.
- Switchyard changes a setting: the microcontroller sets the new value and the LED ring jumps to show it. Nothing physical has to move, and the next turn of the knob carries on from the new value.
- Power off and on: the pedal remembers its last settings and starts up exactly as it was left. That’s important for standalone use, since an endless knob has no position to read at power-up.
- In the audio circuit, each knob’s setting is applied by a digital potentiometer: a chip that acts as a variable resistor, set by the microcontroller. Flashover uses three Microchip MCP45HV51 chips (100k for Gain, 10k for Tone and Level), which handle the full 9V signal range.
- The knobs are rotary encoders with a push switch (Bourns PEC11R type, 24 steps per turn).
- The LED rings have 11 LEDs each, from about 7 o’clock to 5 o’clock, with LED 6 at 12 o’clock so Tone’s middle position has its own LED. Gain and Level can show a bar and Tone a single dot. One LED driver chip (IS31FL3236A) runs all three rings plus the Soft, Hard and On LEDs, and can dim them for dark stages.
- Still to decide on the prototype: LED color and brightness, and whether pressing a knob resets it to a default.

Circuit note: digital pots that work at 9V only go up to about 100k, but the Distortion+ gain knob is 1M. The gain stage is scaled down by ten: 1M to 100k, 4.7k to 330 ohms (less than 470 to allow for the digital pot’s own wiper resistance, about 150 ohms at 9V according to its datasheet), and the capacitor in that leg up from 47n to 470n to keep the same bass response. The gain range is unchanged: about 1.8× to 170× at 1 kHz.

# Working with Switchyard

Flashover follows the Linework Control Specification, which defines how every Linework pedal connects to Switchyard. The main points for Flashover:

## Connection: a loop back to Switchyard

- Flashover has a MIDI in and a MIDI out jack (3.5 mm TRS).
- The pedals are connected in a loop: Switchyard’s MIDI out goes to the first pedal’s MIDI in, each pedal’s MIDI out goes to the next pedal’s MIDI in, and the last pedal’s MIDI out goes back to Switchyard’s MIDI in.
- Each pedal passes on everything it receives and adds its own messages, such as a knob turned by hand. So Switchyard needs only one MIDI output however many pedals are connected, and it hears back from all of them.

## Channel: assigned automatically

- Every MIDI message carries a channel number from 1 to 16, and each pedal acts only on its own channel. Up to 16 pedals can be controlled independently.
- Switchyard assigns channels itself. When the pedals are connected, it counts them around the loop and asks each one to identify itself. Each pedal answers with its model, its position in the loop and a unique serial number, and Switchyard gives each one a channel, which the pedal remembers.
- Because each pedal knows its position, Switchyard and the app also know the physical order of the pedals on the board.
- Manual fallback: holding the footswitch while plugging in power puts Flashover in setup mode. Turning the Gain knob picks a channel from 1 to 16, shown on its LED ring, and pressing the footswitch saves it.

## Messages

MIDI message | Sets | Values
Control change 20 | Gain | 0–127 (fully down to fully up)
Control change 21 | Tone | 0–127
Control change 22 | Level | 0–127
Control change 80 | Effect on/off | 0–63 off, 64–127 on
Control change 81 | Clipping mode | 0 Soft, 1 Hard
Program change 0–127 | Recall a stored preset | Presets 1–128

These numbers follow the shared mapping in the Linework Control Specification: knobs from control change 20 upward in panel order, on/off at 80, mode switches from 81. When a setting is changed by hand on the pedal, Flashover sends the same message back to Switchyard.

- Speed: a full update for one pedal (five messages) takes about 5 ms. Updating six pedals takes roughly 30 ms, which feels instant.

# Presets

Flashover stores its own presets, so a single short message can recall a complete sound.

- 128 preset slots, each holding Gain, Tone, Level, clipping mode and on/off. That’s about 6 bytes per preset, under 1 KB in total, so it fits easily in the memory the microcontroller already needs. There is no extra hardware cost.
- Recalling: a MIDI program change message (preset 1–128) loads the preset instantly. Switchyard uses this when stepping through a setlist, and it also lets other brands’ MIDI controllers use Flashover’s presets.
- Saving: presets are written by the app through Switchyard, including “save the current sound” after a player has adjusted the knobs by hand. The app keeps the master copy of every preset and keeps the pedal in sync.
- The cost is in software: pedal firmware to store and recall presets, and app logic to keep the pedal’s copy in sync with the setlists.

# Firmware updates

Flashover’s software can be updated after it’s sold, without opening the pedal. This lets us fix bugs, add features and update the shared MIDI mapping later.

- How an update arrives: the app downloads the new firmware from the Greywire server and sends it over USB to Switchyard. Switchyard sends it to Flashover over the MIDI loop, addressed to that pedal only, and Flashover confirms back over the loop when it’s done.
- Can’t brick the pedal: the memory holds two copies of the firmware. The update is written to the spare copy and checked before the pedal switches to it. If anything goes wrong (for example the power is pulled halfway through), the pedal keeps running the old version.
- Recovery mode: holding the footswitch and the Soft/Hard button while plugging in power starts a minimal recovery program that waits for an update. This is a last resort if the main firmware ever fails to start.
- Time: MIDI is slow, so an update of roughly 100–200 KB takes about one to two minutes per pedal. The app shows progress, and the pedal passes audio in bypass while updating.
- Cost: no extra hardware. The microcontroller’s memory has room for two copies of the firmware.

# Hardware outline

Item | Detail
Jacks | Guitar input, amp output (1/4"); MIDI in and MIDI out (3.5 mm TRS); 9V DC power (2.1 mm, center negative)
Bypass | Relay true bypass (Omron G6K-2) so the microcontroller (and Switchyard) can turn the effect on and off. With the relay off, including when there is no power, the input jack connects straight to the output jack. The firmware turns Level down for a few milliseconds while the relay switches, to avoid clicks
Footswitch | Soft-touch momentary switch read by the microcontroller (instead of a clicky mechanical 3PDT switch)
Knobs | Three endless rotary encoders with push switches (Bourns PEC11R type), each with an 11-LED ring
Digital pots | Three Microchip MCP45HV51 (I²C): 100k for Gain, 10k for Tone and Level
LED driver | One IS31FL3236A (36 outputs): the three rings (33 LEDs) plus the Soft, Hard and On LEDs. It has its own I²C bus because its addresses may overlap the digital pots’
Soft / Hard | Push button, an Omron G6K-2 relay to select the diode pair, and two LEDs labelled Soft and Hard
Microcontroller | Raspberry Pi RP2040 with 2 MB of flash memory (two copies of the firmware, settings and 128 presets) and a 12 MHz crystal. Reads the knobs, button and footswitch, drives the LEDs, handles MIDI, and sets the digital pots, diode switching and bypass relay. A small programming header loads the first firmware; later updates come over MIDI. Nine pins are left spare
MIDI | MIDI in through an H11L1 optocoupler, so pedals stay electrically separate. MIDI out uses the values in the MIDI Association’s 3.3V update
Power | 9V input with reverse-polarity protection, a buffered 4.5V reference for the audio circuit, an L7805 5V regulator (relays and LEDs) and an AP2112K 3.3V regulator (microcontroller and logic)
Enclosure | Hammond 1590BB (about 119.5 × 94 mm), larger than a typical single pedal to fit three LED rings, the button and five jacks. All five jacks are on the top (back) edge
Power draw | Estimated up to about 200 mA at 9V with all LEDs lit (the LED rings are most of it), to be measured on the prototype. At that current the 5V regulator gets warm (about 0.8 W) and may need a small heatsink

# Schematic

The Flashover schematic (version 0.1, October 2026) is split into two KiCad projects, one for each circuit board: pedals/distortion/kicad/Flashover (main board) and pedals/distortion/kicad/Flashover_Controls (control board). The audio sheets match the LTspice model value for value.

Sheet | Board | Contents
Bypass | Main | Input and output jacks, bypass relay, footswitch
Input and Gain | Main | Input network and the GS1 gain stage with the Gain digital pot
Clipping | Main | Soft (germanium) and Hard (silicon) diode pairs and their relay
Tone and Output | Main | DS-1 style tone control, ×4 output amplifier, Tone and Level digital pots
Power and Bias | Main | 9V input, 4.5V reference, 5V regulator, op-amp power
Controller | Main | RP2040, 3.3V regulator, flash memory, crystal, programming header, pin plan
Digital Pots | Main | Control side of the three digital pots
MIDI | Main | MIDI in and MIDI out on 3.5 mm TRS jacks
Board Connector | Both | The 20-pin connector between the boards (J7 on the main board, J8 on the control board) and the mounting holes
Controls | Control | Three encoders and the Soft/Hard button
LED Rings | Control | LED driver, three 11-LED rings, Soft, Hard, On and Link LEDs

# Circuit boards

Flashover is built on two 4-layer circuit boards stacked inside the enclosure (October 2026):

Board | What is on it
Control board | Sits just under the top panel. The three knobs with their LED rings, the LED driver, the Soft/Hard button and the four panel LEDs
Main board | Sits below the control board. The audio circuit, microcontroller, digital pots, MIDI, bypass relay, power, and all five jacks along the top edge

- Connection: the control board plugs into the main board through a 20-pin connector carrying 5V, 3.3V and ground, the LED driver’s I²C bus, the knob and button signals, and the Link LED. Two M3 spacers hold the boards together.
- Panel layout (looking down): Gain and Level side by side at the top with Tone below and centred, the Soft/Hard button at the lower left with its LEDs above it, the On LED above the footswitch and the Link LED under the Level knob.
- Layers: each board has a solid ground layer inside it, which keeps the audio quiet. The main board also has a 3.3V layer for the logic; the control board has a 5V layer for the LEDs.
- To check against real parts before ordering: jack spacing (about 1 mm between the jack bodies), the enclosure’s wall and screw-post sizes, the height between the boards, the panel holes or light pipes for the ring LEDs, and the encoder footprint.

Datasheet checks (October 2026):

- LED current: the driver’s maximum current is 58.5 × 1.3V ÷ R33, so R33 = 15k gives about 5 mA per LED. The firmware can scale it down and dim with PWM.
- LED driver logic: its inputs read anything above 1.4V as high, so 3.3V logic works while the chip runs from 5V. Its I²C addresses (0x3C–0x3F) are the same as the digital pots’, which confirms it needs its own bus.
- MIDI out: 33 ohms on pin 4 and 10 ohms on pin 5 match the MIDI Association’s 3.3V update (CA-033). The 33 ohm resistor should be rated 0.5W.
- Relay coil: the G6K is polarity-sensitive, with pin 1 positive. Both relays are wired that way.
- Digital pots at 9V: the MCP45HV51’s analog side is specified from 10V, and Flashover runs it at about 8.6V. It still works there (it only resets below 6V), but its wiper resistance is about 150 ohms instead of 75. Only the Gain pot is sensitive to that, and R4 was reduced from 390 to 330 ohms to allow for it. To be confirmed on the breadboard.

# Estimated parts cost

Item | Est. cost
Analog circuit (op-amps, diodes, resistors, capacitors) including tone stage and buffer | $5–10
Digital pots (3 knobs) | $3–7
Endless knobs (3 rotary encoders) | $3–6
LED rings (LEDs and driver chip) | $4–10
Soft/Hard button, both diode pairs, switching and two LEDs | $2–4
Microcontroller, memory, crystal | $2–4
MIDI in/out circuit and jacks | $2–4
Bypass relay and footswitch | $4–8
Audio jacks, power jack, regulation, status LEDs | $4–7
Enclosure and circuit board | $8–17
Total parts | about $37–77

Presets and firmware updates add no parts; they use memory the microcontroller already has.

# Certification

- The microcontroller makes Flashover a Class B digital device in the US, which needs a self-declared FCC emissions test (about $1k–3k, one time).
- No Wi-Fi or Bluetooth, and no USB, so no radio or USB costs.
- Selling in Europe or the UK adds CE/UKCA, RoHS and WEEE requirements, as described in the General Concept document.

# Simulation results

The Flashover audio path is simulated in LTspice (pedals/distortion/sim/Flashover_*.cir, October 2026):

Check | Result
Digital pot voltages | Every pot terminal stays between about 3.4V and 5.5V, inside the 0–9V limit
Gain range | About 1.8× to 172× at 1 kHz, the same as GS1 (simulated with a 75 ohm wiper; about 170× with the datasheet’s 150 ohms and R4 = 330)
Soft vs Hard loudness | Hard is about 8.5 dB louder at full Gain (7.7 dB at half Gain). Level × 0.376 in Hard mode matches them within 0.1 dB
Output level | At full Gain and Level: about +6 dB (Soft) and +14.5 dB (Hard) above the guitar signal
Tone pot value | A 10k pot gives tone curves within about 3 dB of the DS-1’s 20k, so 10k is used (20k isn’t available as a 9V digital pot)
Tone range | Dark boosts bass and cuts treble, the middle setting scoops the mids like a DS-1, and bright lifts the treble

Listening files (Flashover_soft.wav and Flashover_hard.wav, matched in loudness) can be generated with Flashover_listen.cir.

# Next steps

- Listen to the simulated Soft and Hard sounds and adjust diode or tone values if needed.
- Breadboard the analog circuit, then add a digital pot, an endless knob with an LED ring and a microcontroller, and control the gain both by hand and from a MIDI source.
- On the breadboard, confirm the digital pots behave as expected from a 9V supply.
- Finish wiring (routing) both circuit boards, check them against the real parts, and order prototype boards.

# Open questions

- LED color and brightness.
- Whether a switching 5V regulator is needed instead of the L7805, once the prototype’s current draw is measured.
- How a player saves a preset without the app, if at all.

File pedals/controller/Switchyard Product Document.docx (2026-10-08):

# Switchyard

Control Pedal — Greywire Linework Series

Item | Detail
Product | Switchyard control pedal
Series | Linework (Greywire Studio)
Status | Draft — basic definition, features still to be narrowed down
Related documents | General Concept.docx; Linework Control Specification.docx; Flashover Product Document.docx

# Overview

Switchyard is the control pedal for the Linework series. A phone (iPhone or Android) plugs directly into it, and it has two main footswitches that step down and up through a list of pre-configured settings. Each step changes the settings of every Linework pedal connected to it at once, so a player can move through the parts of a song, or from one song to the next, with a single tap.

Settings are created in a phone app. Switchyard stores them, so once they’re loaded it keeps working on stage even if the phone is disconnected.

This first version is control only: no audio passes through Switchyard. The phone-based digital effects described in the General Concept document (reverb, delay and so on) are a possible later version.

# Name

A switchyard is the part of a power grid or rail network where switches route lines to where they need to go. That’s what this pedal does for the rest of the pedalboard. It also fits the wire theme of Greywire Studio and the Linework series.

A web search in October 2026 found no guitar product using the name. That isn’t a trademark clearance, so a proper trademark search is still needed before committing to it.

# How it’s used

## Setting up (at home, with the phone)

- The player builds a setlist in the app: a list of songs, each with one or more parts (for example intro, verse, chorus, solo).
- Each part stores the settings for every connected pedal, for example “Flashover on, gain 70%, tone 40%, level 60%.”
- The app sends the setlist to Switchyard, which stores it in its own memory.

## Playing (on stage)

- Right footswitch (Up): move to the next part. After the last part of a song, it moves to the first part of the next song.
- Left footswitch (Down): move back to the previous part.
- Each step sends the new settings to every connected pedal. The change is instant and doesn’t depend on the phone or any network.
- A small display on Switchyard shows the current song and part, so the player doesn’t need to look at the phone.
- If the phone is plugged in, the app shows the same position and can be used to jump straight to any song.

# Connections

Connection | Purpose
USB-C | Connects the phone. Used to load setlists, edit settings and show the current position in the app
MIDI out (3.5 mm TRS) | Start of the MIDI loop: connects to the first pedal’s MIDI in. Each pedal’s MIDI out connects to the next pedal’s MIDI in
MIDI in (3.5 mm TRS) | End of the MIDI loop: the last pedal’s MIDI out connects back here, so Switchyard hears from every pedal
9V DC power | Standard pedal power: 2.1 mm barrel, center negative

Phones: iPhone 15 and later, and Android phones, use USB-C directly. Older Lightning iPhones need Apple’s camera adapter. The pedal could include a clip or cradle to hold the phone; see Open Questions.

# How it talks to the phone and the pedals

The details are defined in the Linework Control Specification, which every Linework pedal follows. In summary:

- To the phone: Switchyard appears to the phone as a standard USB MIDI device. iPhone and Android both support this without drivers or Apple’s MFi licensing program. The app sends setlists, presets and firmware updates, and receives footswitch presses and the pedals’ current settings over this connection.
- To the pedals: a MIDI loop. Messages go out from Switchyard, through every pedal in turn, and back to Switchyard. Each pedal passes on what it receives and adds its own messages. One output and one input serve any number of pedals, up to 16.
- Automatic setup: Switchyard counts the pedals around the loop, asks each one to identify itself and assigns each a MIDI channel. The app then shows the pedals in the order they’re cabled.
- Stepping through a setlist: each pedal stores the settings for each song part as one of its 128 presets, written there by the app. Stepping to the next part sends one short “program change” message per pedal, so even a large board changes in under 10 ms.
- Hand adjustments are reported back. If a player turns a knob on a pedal, the pedal tells Switchyard, so the app can show the change and save it to the current part.
- Firmware updates: the app downloads updates and sends them through Switchyard to each pedal over the loop. Switchyard itself is updated directly over USB.
- Because it uses standard MIDI, Switchyard could also control MIDI pedals from other brands. That’s a possible selling point to look at later.

# Hardware outline

Part | Notes | Est. cost
Microcontroller | e.g. Raspberry Pi RP2040, with memory to store setlists. Has USB built in | $2–4
USB-C connector and protection | Standard parts | $1–2
MIDI out and in circuits, two TRS jacks | A few resistors, an optocoupler for the input, and two 3.5 mm jacks | $2–4
Footswitches (2) | Soft-touch momentary switches; quieter and longer-lasting than clicky latching ones | $4–8
Display | Small OLED or LED display showing song and part | $3–8
Power input and regulation | 9V jack, reverse-polarity protection, 3.3V regulator | $2–4
Enclosure | Wide enough for two footswitches spaced for feet, e.g. Hammond 1590BB size | $8–15
Circuit board, LEDs, hardware | | $3–6
Total parts | | about $26–52

# Certification

- No Wi-Fi or Bluetooth, so no radio certification or Bluetooth fees.
- The microcontroller and USB make it a Class B digital device in the US, which needs a self-declared FCC emissions test (about $1k–3k, one time).
- USB vendor ID: $0 using a free product ID from the chip maker (Raspberry Pi offers these for the RP2040).
- Selling in Europe or the UK adds CE/UKCA, RoHS and WEEE requirements, as described in the General Concept document.

# Phone app (minimum features)

- Create and edit setlists, songs and parts.
- Set each pedal’s values for each part.
- Send the setlist to Switchyard and the matching presets to each pedal, and confirm they saved.
- Show the connected pedals in board order, and save a pedal’s hand-adjusted settings to the current part.
- Download and install firmware updates for Switchyard and the pedals.
- Show the current song and part live, and jump to any song.

# Open questions

- Should holding a footswitch do something extra, such as jump to the next or previous song instead of the next part?
- Should the list stop at the end of the setlist, or wrap around to the start?
- How should the phone be mounted: a built-in cradle, a clip, or just a short cable?
- Should Switchyard charge the phone while connected? Possible, but it adds a USB-C power controller and design complexity.
- Should it run from the phone’s USB power when no 9V supply is connected, for editing at home?
- Should Switchyard offer a second MIDI loop for very large boards?
- Should it have a third footswitch or an expression pedal input later?
- Will a later version carry audio for the phone-based digital effects from the General Concept document?

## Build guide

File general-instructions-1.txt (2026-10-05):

1. Choose a starting circuit

For a first pedal, I'd base it on the MXR Distortion+ design. It's the classic beginner distortion:
- one op-amp gain stage, with a knob that sets how hard it drives
- two clipping diodes to ground, which create the distortion
- a volume knob
- about 15–20 parts in total

Proven circuits like this are widely studied and modified. Once it works, you can make it your own by changing the diodes, adding a tone control and so on. Just don't use the MXR name on your product.

2. Simulate it in LTspice (sim/ folder)

This is where you try diode types and gain ranges, and look at the clipped waveform. Even listen to it as a .wav file, before buying anything.

3. Build it on a breadboard

I strongly recommend this before making a board. The parts cost roughly $15–30 if you don't already have them, and you'll find mistakes cheaply. You'll also want a 9V supply and a guitar and amp to test with.

4. Draw the schematic in KiCad

Open GS1.kicad_sch and do the following:
1. Place the parts and wire them up.
2. Assign each part a footprint, which is its physical size and pad layout on the board.
3. Run the Electrical Rules Check to catch wiring mistakes.

5. Lay out the board

Open GS1.kicad_pcb and size the board to fit a standard enclosure (a Hammond 1590B is the usual small pedal box). Then do the following:
1. Place the jacks, knobs and footswitch.
2. Route the copper traces between parts.
3. Run the Design Rules Check.

6. Order the boards

Export Gerber files and upload them to JLCPCB or PCBWay.

How I can help with step 2: LTspice can run a circuit written as a text netlist. I can write one for a Distortion+-style circuit and put it in sim/. Then you just open it in LTspice and press Run to see the clean and distorted signals. Want me to do that?

I haven't committed the new KiCad project yet. I can commit it now or wait until there's something drawn in it.

That window is KiCad's Project Manager, its home screen. The left side lists your project's files, and the right side has buttons that open KiCad's editing tools.

The three files

GS1.kicad_pro: the project file
This holds project-wide settings like design rules, default trace widths and which libraries to use. You rarely edit it directly. It's roughly like a package.json: it ties the project together, and opening it opens the whole project.

The [main] next to it is your git branch. Recent KiCad versions have built-in git support, so KiCad noticed the GreywireStudio repo and shows the branch you're on. You can keep using git from the command line (or I can run it for you) and ignore that feature.

GS1.kicad_sch: the schematic
This is the circuit diagram: which parts exist and how they're connected. It shows the electrical logic, not physical layout. Here a resistor is just a zigzag symbol, and a wire is just a line meaning "these two points are connected." This is where you'll start.

GS1.kicad_pcb: the circuit board layout
This is the physical board: where each part sits, its real size, and the copper traces between parts. The board makers manufacture from this file. It's built from the schematic, so you finish the schematic first and then KiCad brings its parts and connections over.

A software analogy: the schematic is like your source code, which describes what the circuit does. The board layout is like the compiled, deployed result, a physical form of that logic. Change the schematic, then update the board from it, never the other way around.

The tool buttons on the right

You'll mainly use two of them:
- Schematic Editor: opens GS1.kicad_sch
- PCB Editor: opens GS1.kicad_pcb

The others you'll need occasionally or never:
- Symbol Editor and Footprint Editor: create custom parts if one isn't in KiCad's built-in libraries. The built-in libraries cover almost everything a pedal needs.
- Gerber Viewer: check your manufacturing files before you order boards.
- Calculator Tools: handy formulas, such as how wide a trace needs to be or what resistor color codes mean.
- Image Converter, Drawing Sheet Editor and Plugin Manager: you can ignore these for now.

Next, open the Schematic Editor. It will be a blank page with a title block in the corner, and that's where the distortion circuit gets drawn.

✻ Cooked for 11s · done 9:43 AM

❯ ok I have opened the schematic editor

The Schematic Editor works like a drawing canvas. You place part symbols, then connect them with wires. Here's how to get around and what to draw first.

Getting around

- Zoom: mouse scroll wheel
- Pan: hold the middle mouse button (scroll wheel) and drag
- Escape: cancels whatever tool you're in. Press it whenever you're stuck.

The shortcuts you'll use 95% of the time

Hover over the canvas and press:

┌────────┬──────────────────────────────────────────────────────────────────┐
│  Key   │                              Action                              │
├────────┼──────────────────────────────────────────────────────────────────┤
│ A      │ Add a part symbol (opens a search window)                        │
├────────┼──────────────────────────────────────────────────────────────────┤
│ P      │ Add a power symbol (+9V, GND)                                    │
├────────┼──────────────────────────────────────────────────────────────────┤
│ W      │ Draw a wire. Click to start, click to bend, double-click to end. │
├────────┼──────────────────────────────────────────────────────────────────┤
│ L      │ Add a net label, a named connection point (explained below)      │
├────────┼──────────────────────────────────────────────────────────────────┤
│ M      │ Move the part under the mouse                                    │
├────────┼──────────────────────────────────────────────────────────────────┤
│ R      │ Rotate the part under the mouse                                  │
├────────┼──────────────────────────────────────────────────────────────────┤
│ V      │ Set a part's value, such as "10k" or "1M"                        │
├────────┼──────────────────────────────────────────────────────────────────┤
│ E      │ Edit all of a part's properties                                  │
├────────┼──────────────────────────────────────────────────────────────────┤
│ Delete │ Delete the thing under the mouse                                 │
├────────┼──────────────────────────────────────────────────────────────────┤
│ Ctrl+S │ Save                                                             │
└────────┴──────────────────────────────────────────────────────────────────┘

Net labels will save you a lot of wiring. Any two points that carry the same label name are connected, even with no wire drawn between them. The GND and +9V power symbols work the same way: every GND symbol is connected to every other one.

The circuit

This is a Distortion+-style circuit, grouped into four sections. "VB" is a net label, a 4.5V reference halfway between 0V and 9V that the op-amp needs.

A. Bias voltage (makes VB)
- R7 1M: from +9V to VB
- R8 1M: from VB to GND
- C6 10µF electrolytic: from VB to GND
- C7 100µF electrolytic: from +9V to GND (smooths the power supply)

B. Input
- J1 input jack: tip goes to the net IN, sleeve goes to GND
- R1 1M: from IN to GND (prevents a pop when you switch the pedal on)
- C1 10nF: from IN to a point we'll call N1
- R2 10k: from N1 to the op-amp's + input
- C2 1nF: from the op-amp's + input to GND (filters out radio noise)
- R3 1M: from the op-amp's + input to VB

C. Gain stage (the op-amp, U1)
- U1 power pins: one goes to +9V, the other to GND
- R5 1M: from the op-amp's output to its − input
- R4 4.7k: from the − input to the Distortion pot
- RV1 Distortion pot, 1M: in series with R4. Use the wiper and one end, so it acts as a variable resistor.
- C3 47nF: from the other side of RV1 to GND

The gain is 1 + R5 ÷ (R4 + RV1). That's about 200× at full distortion and about 2× at minimum.

D. Output and clipping
- C4 1µF: from the op-amp's output to a point we'll call N2
- R6 10k: from N2 to the net CLIP
- D1 and D2: from CLIP to GND, one pointing each way (this is where the distortion comes from)
- C5 1nF: from CLIP to GND
- RV2 Volume pot, 10k: one end to CLIP, the other end to GND, and the wiper to the output jack's tip
- J2 output jack: tip from RV2's wiper, sleeve to GND

What to type in the search window (after pressing A)

┌───────────────┬──────────────────────────────────────────────────┐
│     Part      │                    Search for                    │
├───────────────┼──────────────────────────────────────────────────┤
│ Resistor      │ R, then pick Device:R                            │
├───────────────┼──────────────────────────────────────────────────┤
│ Capacitor     │ Device:C (for electrolytics, Device:C_Polarized) │
├───────────────┼──────────────────────────────────────────────────┤
│ Potentiometer │ Device:R_Potentiometer                           │
├───────────────┼──────────────────────────────────────────────────┤
│ Diode         │ Device:D                                         │
├───────────────┼──────────────────────────────────────────────────┤
│ Op-amp        │ 741, in the Amplifier_Operational library        │
├───────────────┼──────────────────────────────────────────────────┤
│ Jack          │ Connector:AudioJack2                             │
└───────────────┴──────────────────────────────────────────────────┘

Your first step

Draw section A only (the bias voltage):
1. Place the four parts.
2. Add the +9V and GND power symbols.
3. Put a VB net label where R7, R8 and C6 meet.
4. Set each part's value with V.
5. Save with Ctrl+S.

Don't worry about neatness. Once you've saved, tell me and I'll read GS1.kicad_sch from the repo to check your connections before you move on to the input section.

Step 1: Place the resistor

1. Press A. The Choose Symbol window opens.
2. In the filter box at the top, type Device:R.
3. In the list, click R under the Device library. Its description says "Resistor", and a preview appears on the right.
4. Click OK. The resistor is now attached to your mouse pointer, standing upright.
5. Click somewhere in the middle of the page to drop it.
6. KiCad may open the symbol chooser again so you can place another part. Press Escape to stop.

Step 2: Set its value to 1M

1. Hover over the resistor and press V.
2. Replace the text with 1M (1 megaohm) and press Enter.

The label next to the resistor should now say 1M.

Step 3: Rename it to R7

KiCad numbers parts automatically, so it probably called this one R1. Rename it to match the list:
1. Hover over the resistor and press E. The Symbol Properties window opens.
2. In the Reference row, change R1 to R7.
3. Click OK.e

Step 4: Connect the top end to +9V

1. Press P to open the power symbol chooser.
2. Type +9V, select +9V from the power library, and click OK.
3. Place it a little above the resistor, then press Escape.
4. Look at the top end of the resistor. There's a small circle at the tip of the pin, which marks an unconnected pin.
5. Hover exactly over that circle and press W to start a wire there.
6. Move the mouse up to the bot click. The wire endsautomatically when it reaches a pin.

The small circles at both ends disappear when they're connected. That's how you can tell a
connection worked.

You can also skip the wire. Drag the +9V symbol so its pin lands exactly on the resistor's pin, and they connect directly.

Step 5: Label the bottom end VB

1. Hover over the circle on the resistor's bottom pin and press W.
2. Move straight down a short distance and double-click to end the wire.
3. Press L. The label window op
4. Type VB and press Enter or click OK.aw
5. The label is attached to youection point (the small square at its tip) sits on the end of the wire you just drew, then click.

Step 6: Save

Press Ctrl+S.

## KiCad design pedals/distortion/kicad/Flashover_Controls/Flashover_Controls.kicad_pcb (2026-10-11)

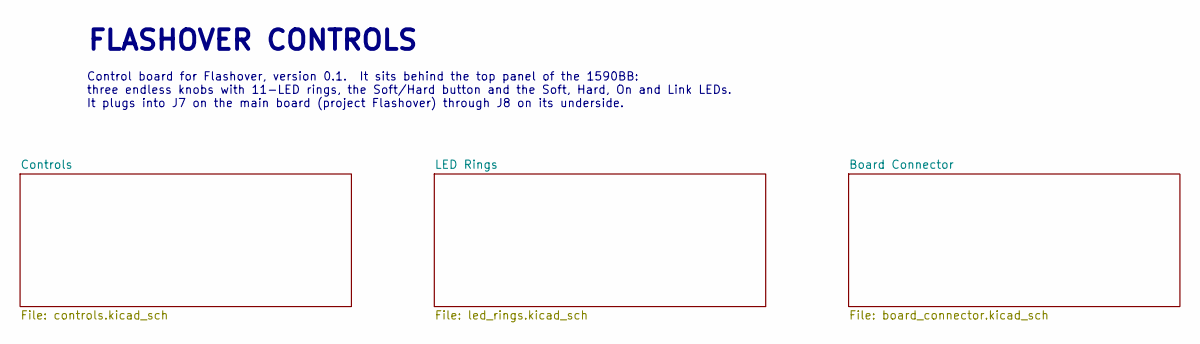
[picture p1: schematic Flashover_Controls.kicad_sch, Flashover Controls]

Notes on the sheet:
FLASHOVER CONTROLS
Control board for Flashover, version 0.1. It sits behind the top panel of the 1590BB: three endless knobs with 11-LED rings, the Soft/Hard button and the Soft, Hard, On and Link LEDs. It plugs into J7 on the main board (project Flashover) through J8 on its underside.

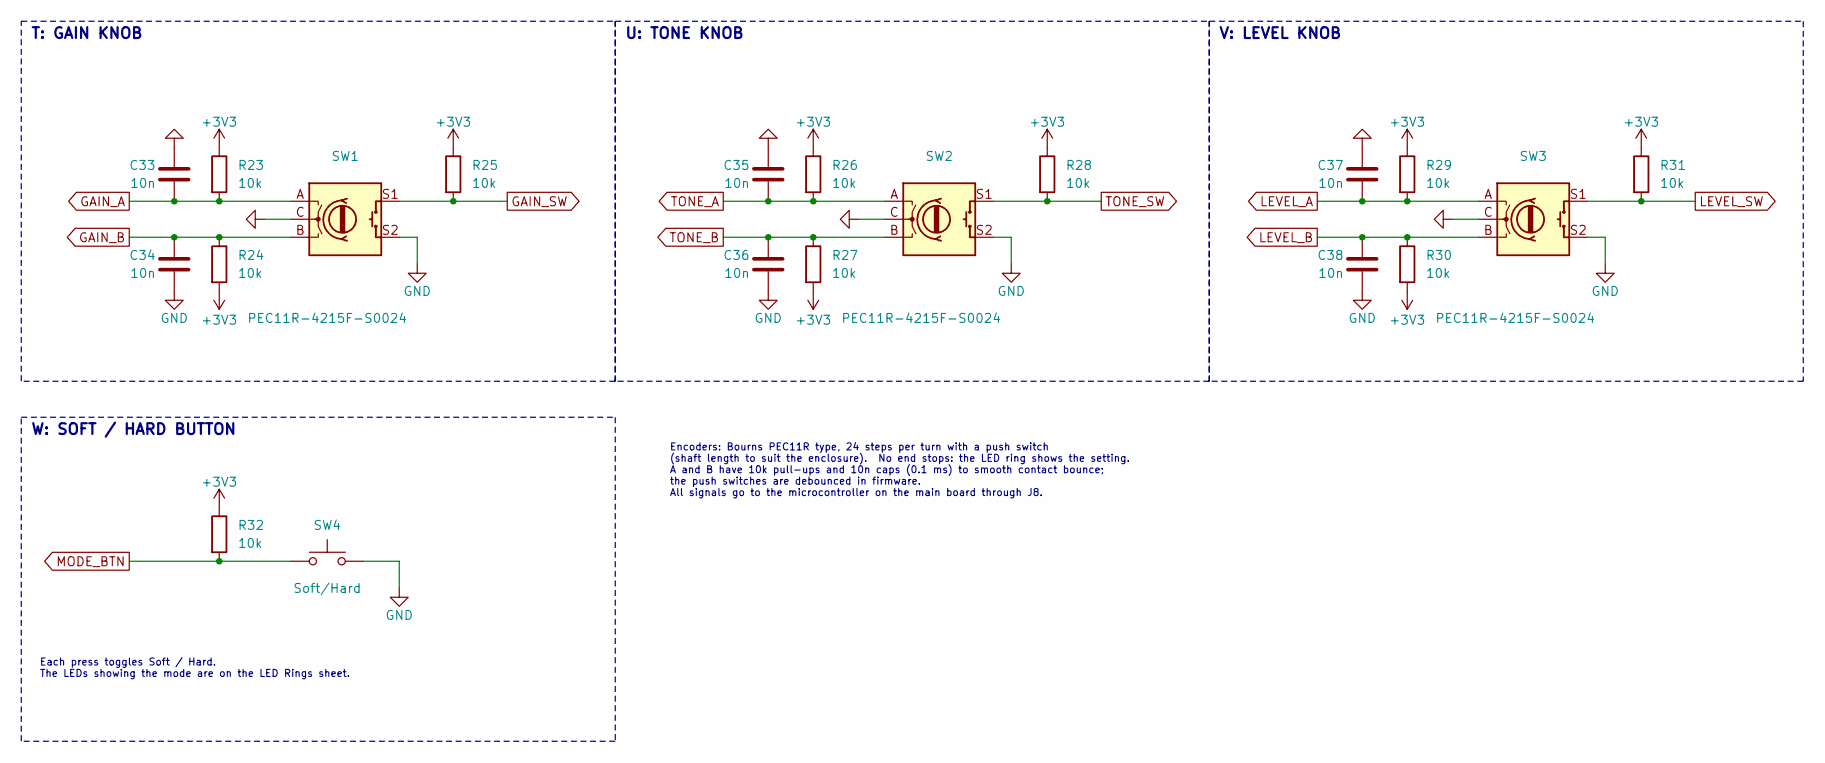
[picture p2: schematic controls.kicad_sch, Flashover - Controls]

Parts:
C33, C34, C35, C36, C37, C38: 10n; C_0805_2012Metric
R23, R24, R25, R26, R27, R28, R29, R30, R31, R32: 10k; R_0805_2012Metric
SW1, SW2, SW3: PEC11R-4215F-S0024; RotaryEncoder_Alps_EC11E-Switch_Vertical_H20mm
SW4: Soft/Hard; SW_PUSH_6mm_H13mm

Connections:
+3V3: R23.1, R24.2, R25.1, R26.1, R27.2, R28.1, R29.1, R30.2, R31.1, R32.1; also elsewhere on the board
GAIN_A: C33.2, R23.2, SW1.A; also elsewhere on the board
GAIN_B: C34.1, R24.1, SW1.B; also elsewhere on the board
GAIN_SW: R25.2, SW1.S1; also elsewhere on the board
GND: C33.1, C34.2, C35.1, C36.2, C37.1, C38.2, SW1.C, SW1.S2, SW2.C, SW2.S2, SW3.C, SW3.S2, SW4.2; also elsewhere on the board
LEVEL_A: C37.2, R29.2, SW3.A; also elsewhere on the board
LEVEL_B: C38.1, R30.1, SW3.B; also elsewhere on the board
LEVEL_SW: R31.2, SW3.S1; also elsewhere on the board
MODE_BTN: R32.2, SW4.1; also elsewhere on the board
TONE_A: C35.2, R26.2, SW2.A; also elsewhere on the board
TONE_B: C36.1, R27.1, SW2.B; also elsewhere on the board
TONE_SW: R28.2, SW2.S1; also elsewhere on the board

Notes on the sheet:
T: GAIN KNOB
U: TONE KNOB
V: LEVEL KNOB
W: SOFT / HARD BUTTON
Each press toggles Soft / Hard. The LEDs showing the mode are on the LED Rings sheet.
Encoders: Bourns PEC11R type, 24 steps per turn with a push switch (shaft length to suit the enclosure). No end stops: the LED ring shows the setting. A and B have 10k pull-ups and 10n caps (0.1 ms) to smooth contact bounce; the push switches are debounced in firmware. All signals go to the microco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

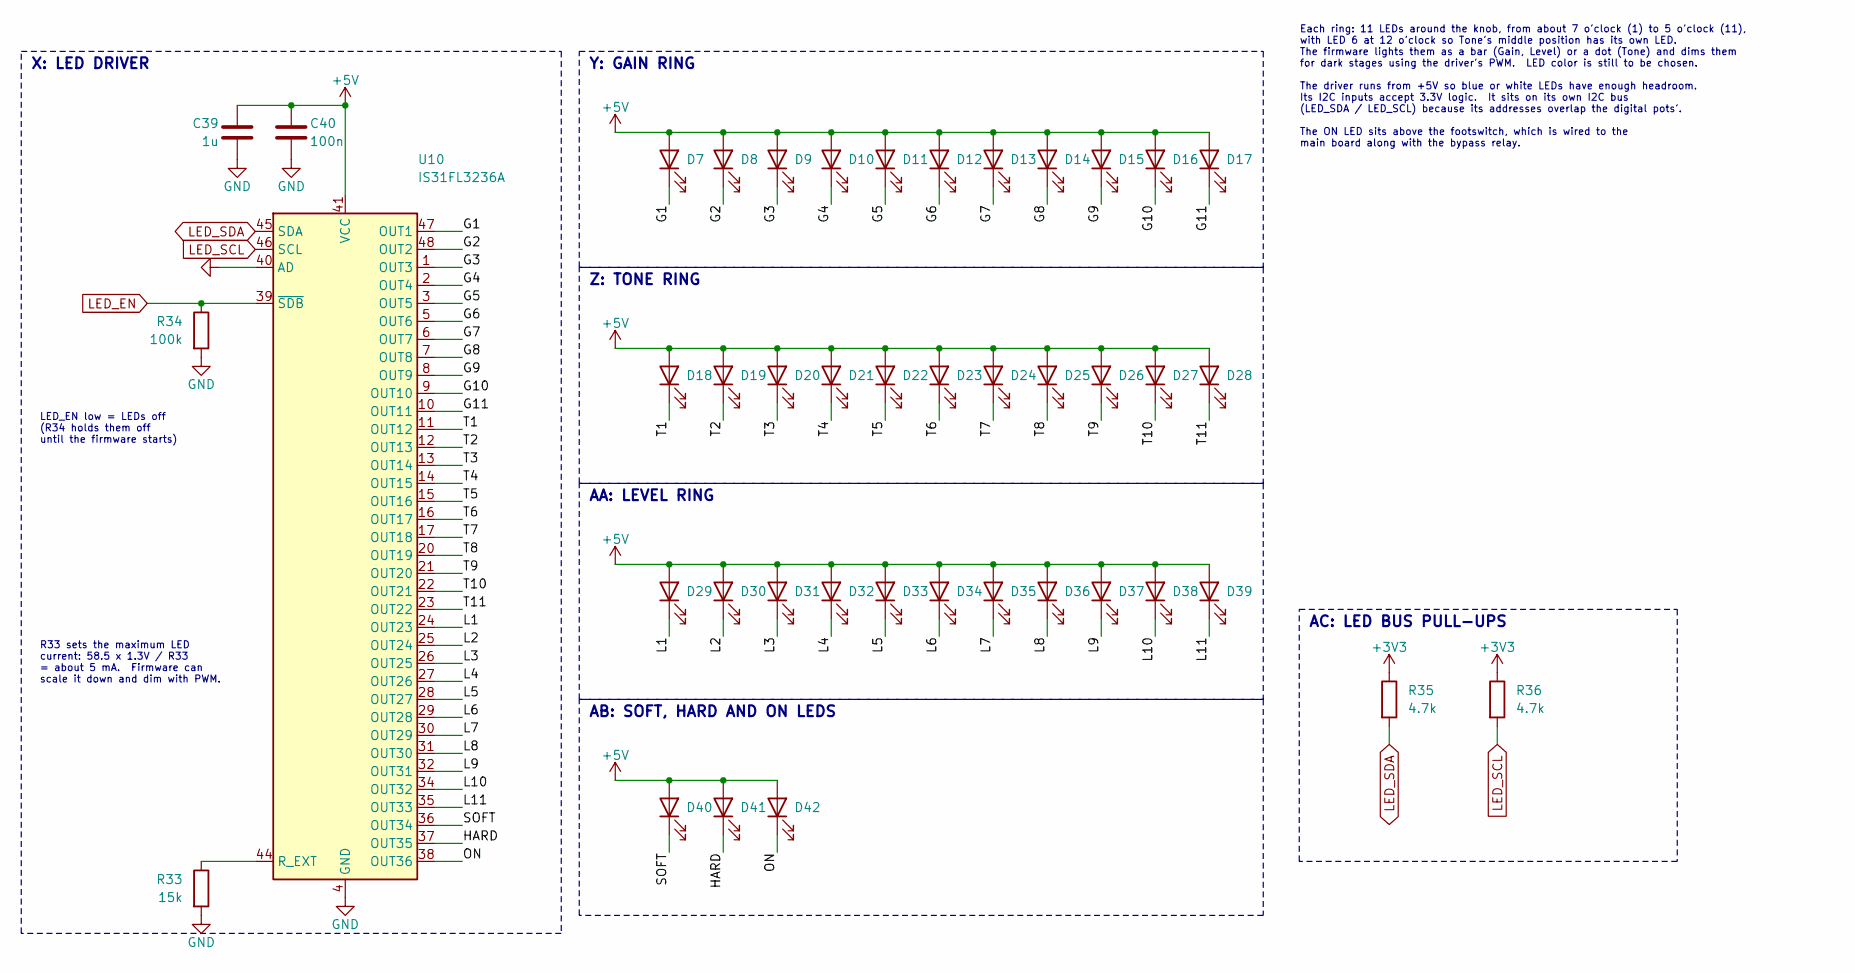
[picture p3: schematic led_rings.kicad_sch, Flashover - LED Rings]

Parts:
C39: 1u; C_0805_2012Metric
C40: 100n; C_0805_2012Metric
D7, D8, D9, D10, D11, D12, D13, D14, D15, D16, D17, D18, D19, D20, D21, D22, D23, D24, D25, D26, D27, D28, D29, D30, D31, D32, D33, D34, D35, D36, D37, D38, D39: LED; LED_0805_2012Metric
D40, D41, D42: LED; LED_D3.0mm
R33: 15k; R_0805_2012Metric
R34: 100k; R_0805_2012Metric
R35, R36: 4.7k; R_0805_2012Metric
U10: IS31FL3236A; TQFP-48-1EP_7x7mm_P0.5mm_EP4.11x4.11mm

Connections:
+3V3: R35.1, R36.1; also elsewhere on the board
+5V: C39.1, C40.1, D7.2 (A), D8.2 (A), D9.2 (A), D10.2 (A), D11.2 (A), D12.2 (A), D13.2 (A), D14.2 (A), D15.2 (A), D16.2 (A), D17.2 (A), D18.2 (A), D19.2 (A), D20.2 (A), D21.2 (A), D22.2 (A), D23.2 (A), D24.2 (A), D25.2 (A), D26.2 (A), D27.2 (A), D28.2 (A), D29.2 (A), D30.2 (A), D31.2 (A), D32.2 (A), D33.2 (A), D34.2 (A), D35.2 (A), D36.2 (A), D37.2 (A), D38.2 (A), D39.2 (A), D40.2 (A), D41.2 (A), D42.2 (A), U10.41 (VCC); also elsewhere on the board
/LED Rings/G1: D7.1 (K), U10.47 (OUT1)
/LED Rings/G2: D8.1 (K), U10.48 (OUT2)
/LED Rings/G3: D9.1 (K), U10.1 (OUT3)
/LED Rings/G4: D10.1 (K), U10.2 (OUT4)
/LED Rings/G5: D11.1 (K), U10.3 (OUT5)
/LED Rings/G6: D12.1 (K), U10.5 (OUT6)
/LED Rings/G7: D13.1 (K), U10.6 (OUT7)
/LED Rings/G8: D14.1 (K), U10.7 (OUT8)
/LED Rings/G9: D15.1 (K), U10.8 (OUT9)
/LED Rings/G10: D16.1 (K), U10.9 (OUT10)
/LED Rings/G11: D17.1 (K), U10.10 (OUT11)
/LED Rings/HARD: D41.1 (K), U10.37 (OUT35)
/LED Rings/L1: D29.1 (K), U10.24 (OUT23)
/LED Rings/L2: D30.1 (K), U10.25 (OUT24)
/LED Rings/L3: D31.1 (K), U10.26 (OUT25)
/LED Rings/L4: D32.1 (K), U10.27 (OUT26)
/LED Rings/L5: D33.1 (K), U10.28 (OUT27)
/LED Rings/L6: D34.1 (K), U10.29 (OUT28)
/LED Rings/L7: D35.1 (K), U10.30 (OUT29)
/LED Rings/L8: D36.1 (K), U10.31 (OUT30)
/LED Rings/L9: D37.1 (K), U10.32 (OUT31)
/LED Rings/L10: D38.1 (K), U10.34 (OUT32)
/LED Rings/L11: D39.1 (K), U10.35 (OUT33)
/LED Rings/ON: D42.1 (K), U10.38 (OUT36)
/LED Rings/SOFT: D40.1 (K), U10.36 (OUT34)
/LED Rings/T1: D18.1 (K), U10.11 (OUT12)
/LED Rings/T2: D19.1 (K), U10.12 (OUT13)
/LED Rings/T3: D20.1 (K), U10.13 (OUT14)
/LED Rings/T4: D21.1 (K), U10.14 (OUT15)
/LED Rings/T5: D22.1 (K), U10.15 (OUT16)
/LED Rings/T6: D23.1 (K), U10.16 (OUT17)
/LED Rings/T7: D24.1 (K), U10.17 (OUT18)
/LED Rings/T8: D25.1 (K), U10.20 (OUT19)
/LED Rings/T9: D26.1 (K), U10.21 (OUT20)
/LED Rings/T10: D27.1 (K), U10.22 (OUT21)
/LED Rings/T11: D28.1 (K), U10.23 (OUT22)
GND: C39.2, C40.2, R33.2, R34.2, U10.4 (GND), U10.18 (GND), U10.19 (GND), U10.33 (GND), U10.40 (AD), U10.42 (GND), U10.43 (GND), U10.49 (GND); also elsewhere on the board
LED_EN: R34.1, U10.39 (~SDB); also elsewhere on the board
LED_SCL: R36.2, U10.46 (SCL); also elsewhere on the board
LED_SDA: R35.2, U10.45 (SDA); also elsewhere on the board
unnamed: R33.1, U10.44 (R_EXT)

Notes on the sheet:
X: LED DRIVER
LED_EN low = LEDs off (R34 holds them off until the firmware starts)
R33 sets the maximum LED current: 58.5 x 1.3V / R33 = about 5 mA. Firmware can scale it down and dim with PWM.
Y: GAIN RING
Z: TONE RING
AA: LEVEL RING
AB: SOFT, HARD AND ON LEDS
Each ring: 11 LEDs around the knob, from about 7 o'clock (1) to 5 o'clock (11), with LED 6 at 12 o'clock so Tone's middle position has its own LED. The firmware lights them as a bar (Gain, Level) or a dot (Tone) and dims them for dark stages using the driver's PWM. LED color is still to be chosen. 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
AC: LED BUS PULL-UPS

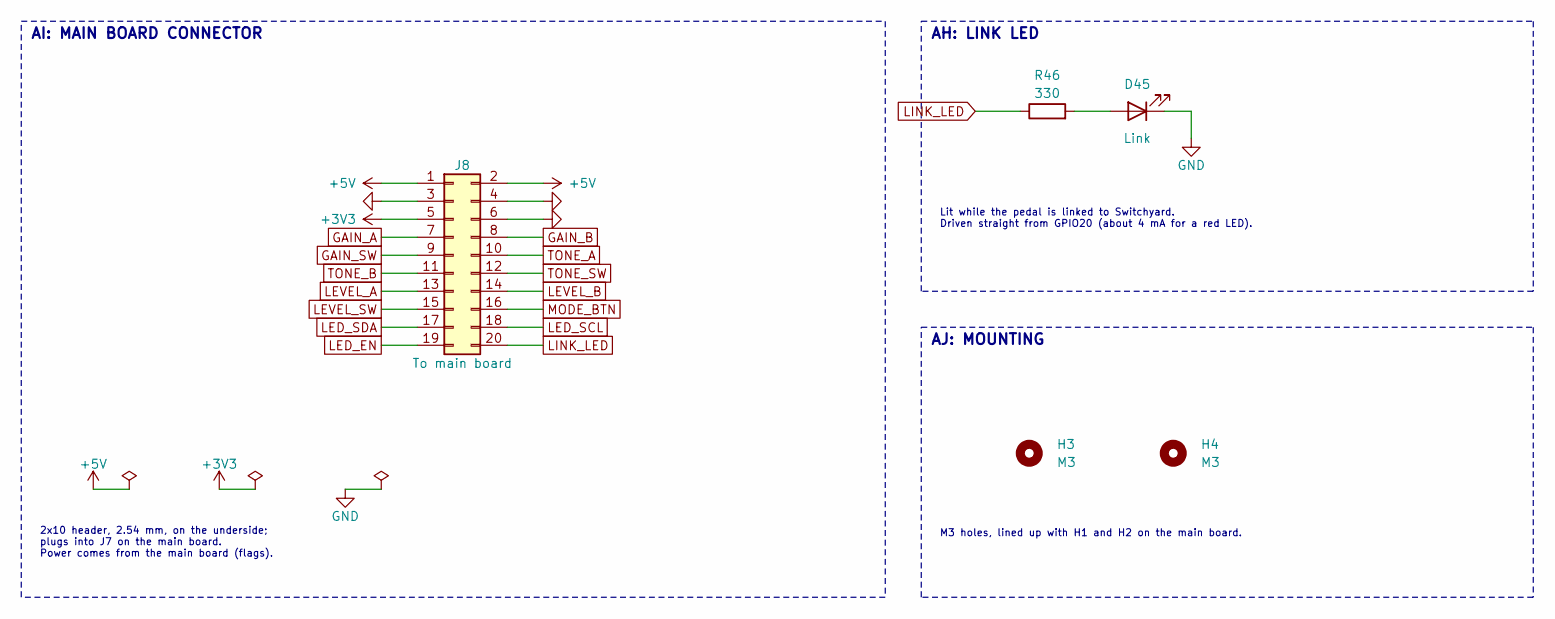
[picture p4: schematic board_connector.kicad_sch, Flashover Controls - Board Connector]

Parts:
D45: Link; LED_D3.0mm
H3, H4: M3; MountingHole_3.2mm_M3
J8: To main board; PinHeader_2x10_P2.54mm_Vertical
R46: 330; R_0805_2012Metric

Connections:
+3V3: J8.5; also elsewhere on the board
+5V: J8.1, J8.2; also elsewhere on the board
GAIN_A: J8.7; also elsewhere on the board
GAIN_B: J8.8; also elsewhere on the board
GAIN_SW: J8.9; also elsewhere on the board
GND: D45.1 (K), J8.3, J8.4, J8.6; also elsewhere on the board
LED_EN: J8.19; also elsewhere on the board
LED_SCL: J8.18; also elsewhere on the board
LED_SDA: J8.17; also elsewhere on the board
LEVEL_A: J8.13; also elsewhere on the board
LEVEL_B: J8.14; also elsewhere on the board
LEVEL_SW: J8.15; also elsewhere on the board
LINK_LED: J8.20, R46.1
MODE_BTN: J8.16; also elsewhere on the board
unnamed: D45.2 (A), R46.2
TONE_A: J8.10; also elsewhere on the board
TONE_B: J8.11; also elsewhere on the board
TONE_SW: J8.12; also elsewhere on the board

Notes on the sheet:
AI: MAIN BOARD CONNECTOR
2x10 header, 2.54 mm, on the underside; plugs into J7 on the main board. Power comes from the main board (flags).
AH: LINK LED
Lit while the pedal is linked to Switchyard. Driven straight from GPIO20 (about 4 mA for a red LED).
AJ: MOUNTING
M3 holes, lined up with H1 and H2 on the main board.

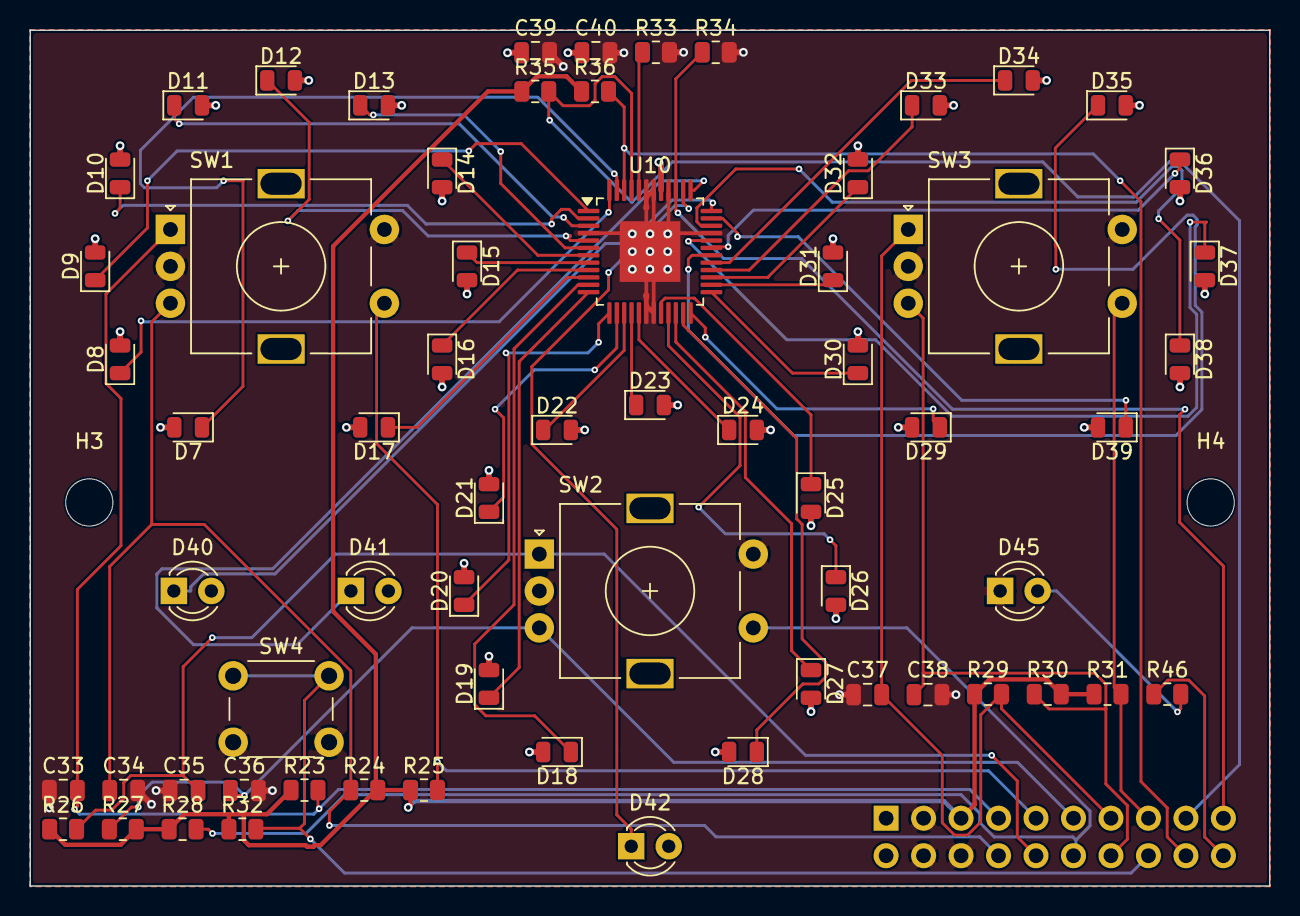
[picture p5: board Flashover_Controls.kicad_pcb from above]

Board: 4 copper layers, 84.0 x 58.0 mm, 68 parts (1 on the bottom side), 55 nets.

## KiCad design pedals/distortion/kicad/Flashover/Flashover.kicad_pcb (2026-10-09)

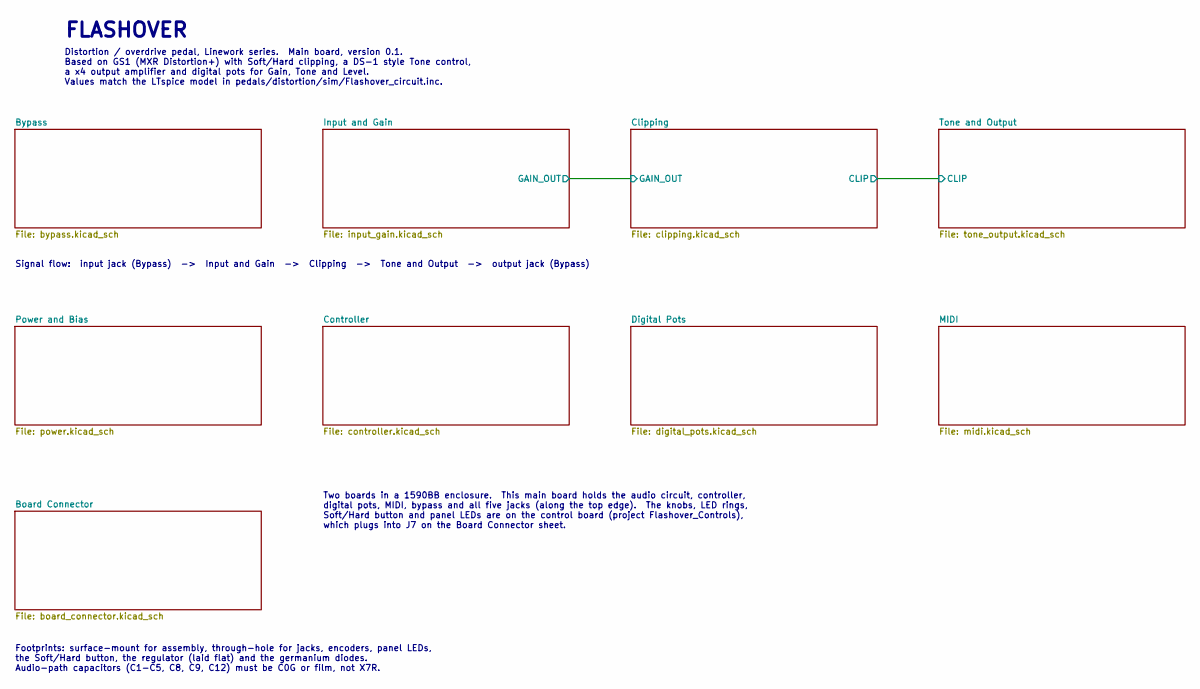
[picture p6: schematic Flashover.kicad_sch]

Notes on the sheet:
FLASHOVER
Distortion / overdrive pedal, Linework series. Main board, version 0.1. Based on GS1 (MXR Distortion+) with Soft/Hard clipping, a DS-1 style Tone control, a x4 output amplifier and digital pots for Gain, Tone and Level. Values match the LTspice model in pedals/distortion/sim/Flashover_circuit.inc.
Signal flow: input jack (Bypass) -> Input and Gain -> Clipping -> Tone and Output -> output jack (Bypass)
Two boards in a 1590BB enclosure. This main board holds the audio circuit, controller, digital pots, MIDI, bypass and all five jacks (along the top edge). The knobs, LED rings, Soft/Hard button and panel LEDs are on the control board (project Flashover_Controls), which plugs into J7 on the Board Co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
Footprints: surface-mount for assembly, through-hole for jacks, encoders, panel LEDs, the Soft/Hard button, the regulator (laid flat) and the germanium diodes. Audio-path capacitors (C1-C5, C8, C9, C12) must be C0G or film, not X7R.

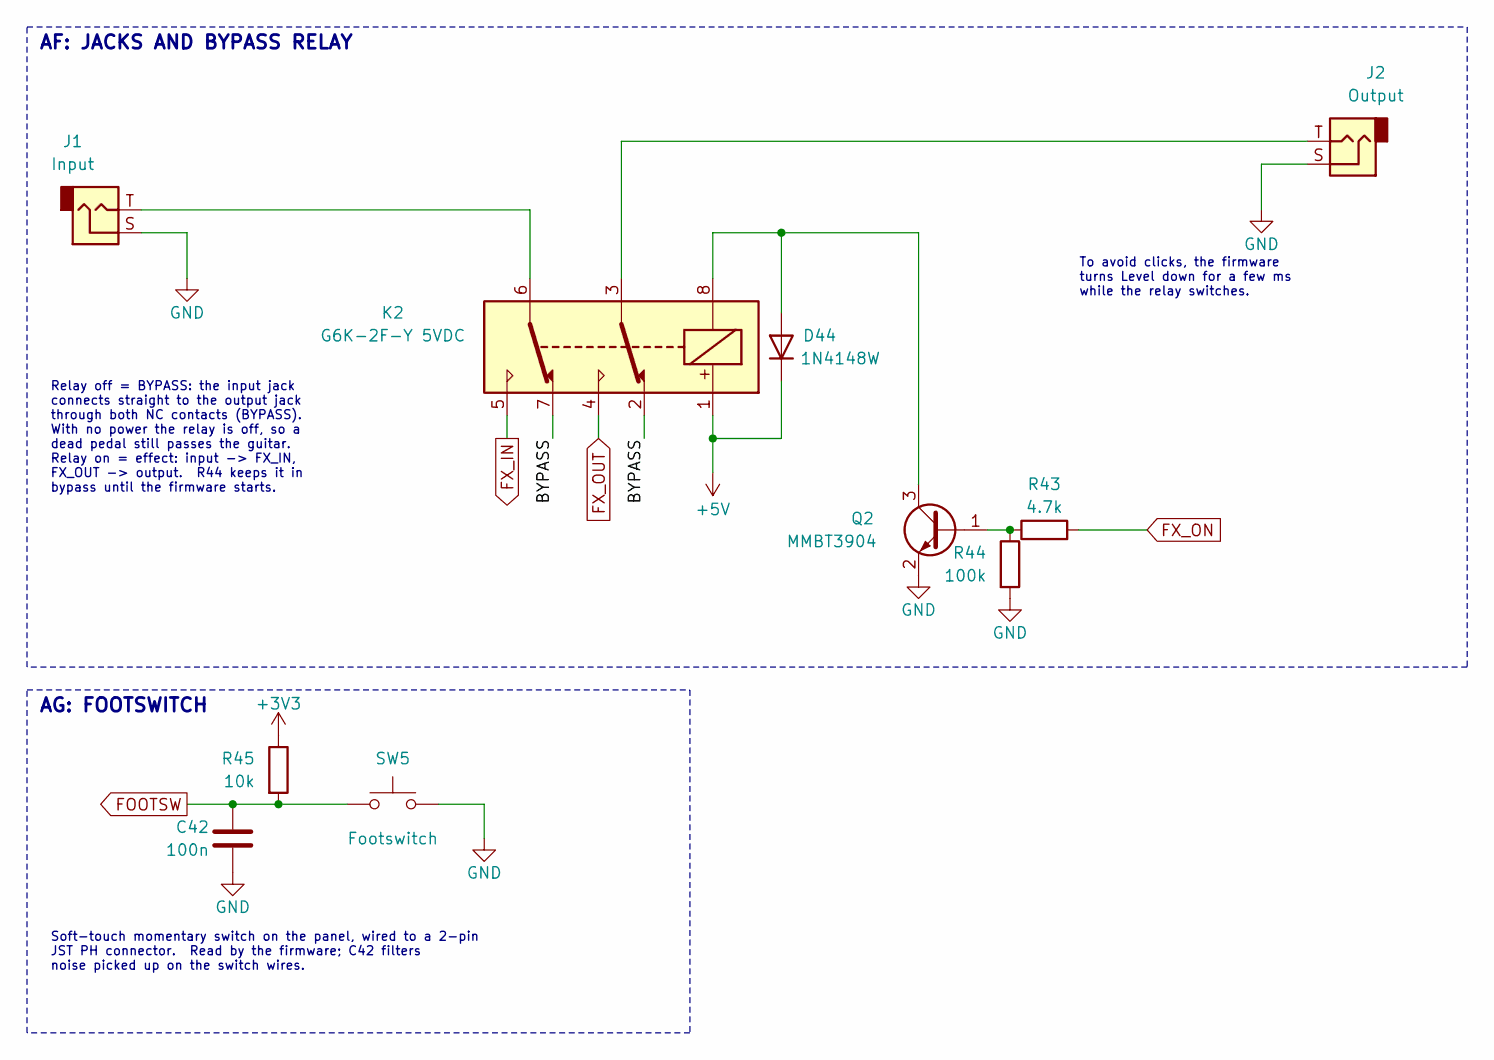
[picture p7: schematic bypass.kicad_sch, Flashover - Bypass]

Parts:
C42: 100n; C_0805_2012Metric
D44: 1N4148W; D_SOD-123
J1: Input; Jack_6.35mm_Neutrik_NRJ4HF_Horizontal
J2: Output; Jack_6.35mm_Neutrik_NRJ4HF_Horizontal
K2: G6K-2F-Y 5VDC; Relay_DPDT_Omron_G6K-2F-Y
Q2: MMBT3904; SOT-23
R43: 4.7k; R_0805_2012Metric
R44: 100k; R_0805_2012Metric
R45: 10k; R_0805_2012Metric
SW5: Footswitch; JST_PH_B2B-PH-K_1x02_P2.00mm_Vertical

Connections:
+3V3: R45.1; also elsewhere on the board
+5V: D44.1 (K), K2.1; also elsewhere on the board
/Bypass/BYPASS: K2.2, K2.7
FOOTSW: C42.1, R45.2, SW5.1; also elsewhere on the board
FX_IN: K2.5; also elsewhere on the board
FX_ON: R43.2; also elsewhere on the board
FX_OUT: K2.4; also elsewhere on the board
GND: C42.2, J1.S, J2.S, Q2.2 (E), R44.2, SW5.2; also elsewhere on the board
unnamed: D44.2 (A), K2.8, Q2.3 (C)
unnamed: J1.T, K2.6
unnamed: J2.T, K2.3
unnamed: Q2.1 (B), R43.1, R44.1

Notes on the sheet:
AF: JACKS AND BYPASS RELAY
AG: FOOTSWITCH
Relay off = BYPASS: the input jack connects straight to the output jack through both NC contacts (BYPASS). With no power the relay is off, so a dead pedal still passes the guitar. Relay on = effect: input -> FX_IN, FX_OUT -> output. R44 keeps it in bypass until the firmware starts.
To avoid clicks, the firmware turns Level down for a few ms while the relay switches.
Soft-touch momentary switch on the panel, wired to a 2-pin JST PH connector. Read by the firmware; C42 filters noise picked up on the switch wires.

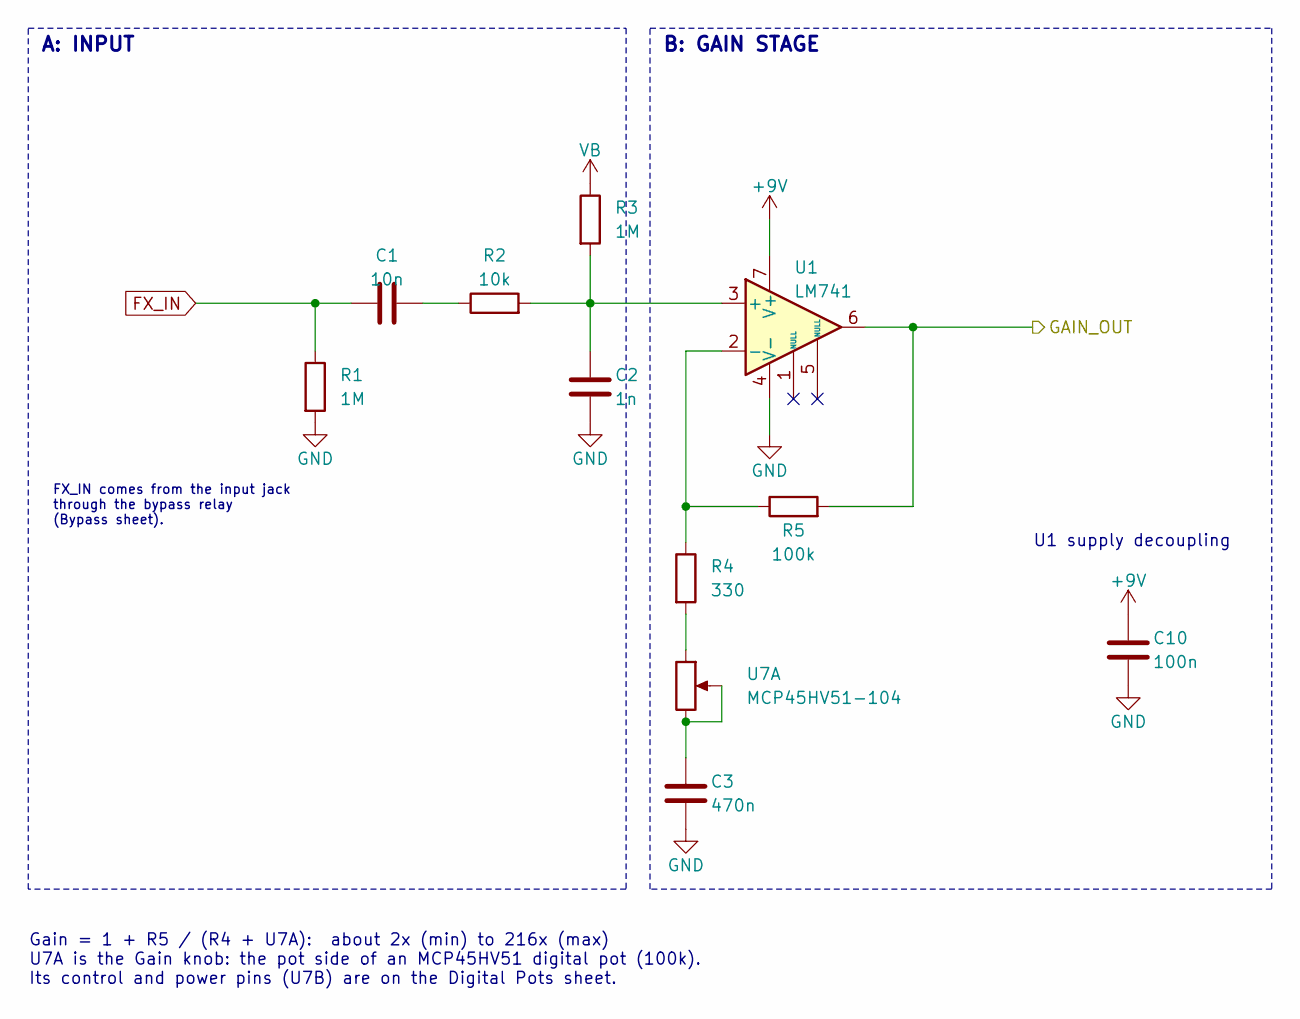
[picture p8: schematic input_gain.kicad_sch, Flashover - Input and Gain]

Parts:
C1: 10n; C_1206_3216Metric
C2: 1n; C_0805_2012Metric
C3: 470n; C_1210_3225Metric
C10: 100n; C_0805_2012Metric
R1, R3: 1M; R_0805_2012Metric
R2: 10k; R_0805_2012Metric
R4: 330; R_0805_2012Metric
R5: 100k; R_0805_2012Metric
U1: LM741; SOIC-8_3.9x4.9mm_P1.27mm
U7: MCP45HV51-104; TSSOP-14_4.4x5mm_P0.65mm

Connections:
+9V: C10.1, U1.7 (V+); also elsewhere on the board
/Clipping/GAIN_OUT: R5.2, U1.6; also elsewhere on the board
FX_IN: C1.1, R1.1; also elsewhere on the board
GND: C2.2, C3.2, C10.2, R1.2, U1.4 (V-); also elsewhere on the board
unnamed: C1.2, R2.1
unnamed: C3.1, U7.11, U7.12
unnamed: R4.2, U7.13
unnamed: C2.1, R2.2, R3.2, U1.3 (+)
unnamed: R4.1, R5.1, U1.2 (-)
VB: R3.1; also elsewhere on the board

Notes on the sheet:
A: INPUT
B: GAIN STAGE
FX_IN comes from the input jack through the bypass relay (Bypass sheet).
U1 supply decoupling
Gain = 1 + R5 / (R4 + U7A): about 2x (min) to 216x (max) U7A is the Gain knob: the pot side of an MCP45HV51 digital pot (100k). Its control and power pins (U7B) are on the Digital Pots sheet.

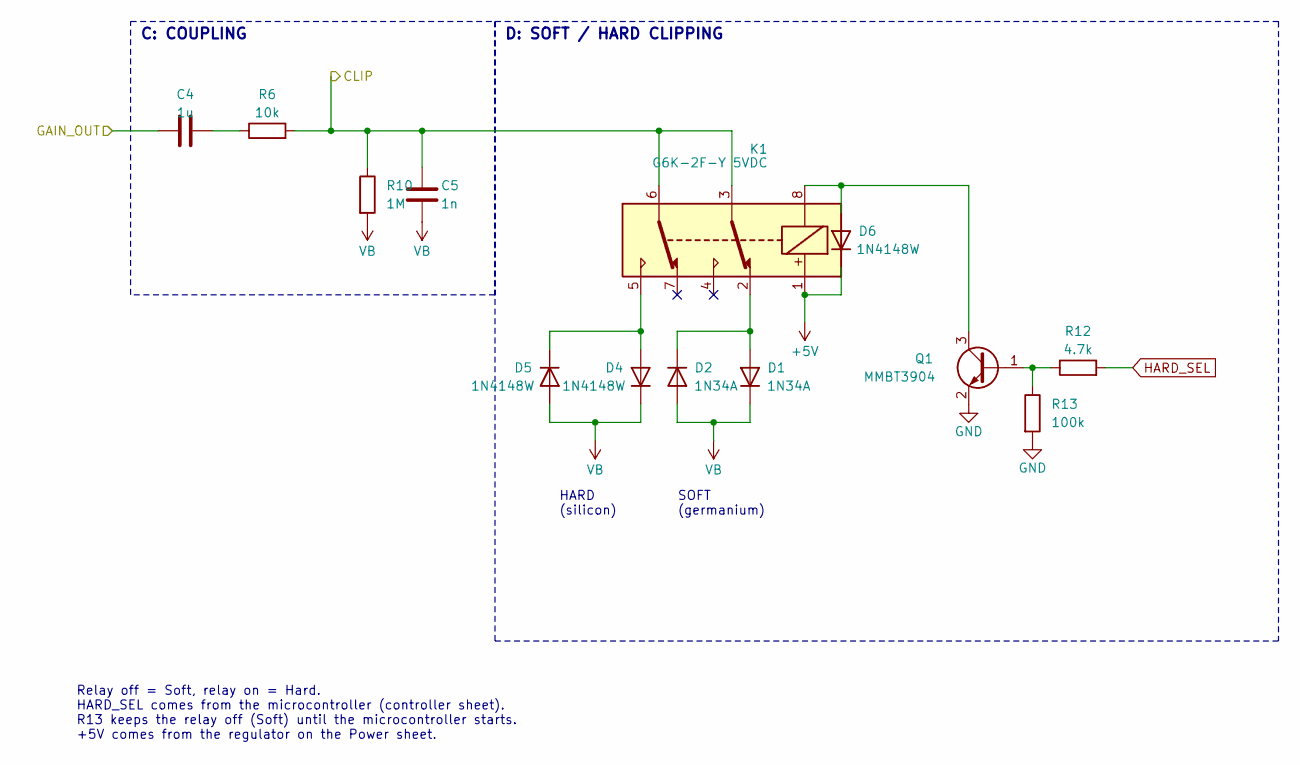
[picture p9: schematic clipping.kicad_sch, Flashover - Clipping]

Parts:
C4: 1u; C_1210_3225Metric
C5: 1n; C_0805_2012Metric
D1, D2: 1N34A; D_DO-35_SOD27_P7.62mm_Horizontal
D4, D5, D6: 1N4148W; D_SOD-123
K1: G6K-2F-Y 5VDC; Relay_DPDT_Omron_G6K-2F-Y
Q1: MMBT3904; SOT-23
R6: 10k; R_0805_2012Metric
R10: 1M; R_0805_2012Metric
R12: 4.7k; R_0805_2012Metric
R13: 100k; R_0805_2012Metric

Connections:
+5V: D6.1 (K), K1.1; also elsewhere on the board
/Clipping/CLIP: C5.1, K1.3, K1.6, R6.2, R10.1; also elsewhere on the board
/Clipping/GAIN_OUT: C4.1; also elsewhere on the board
GND: Q1.2 (E), R13.2; also elsewhere on the board
HARD_SEL: R12.2; also elsewhere on the board
unnamed: C4.2, R6.1
unnamed: D1.2 (A), D2.1 (K), K1.2
unnamed: D4.2 (A), D5.1 (K), K1.5
unnamed: D6.2 (A), K1.8, Q1.3 (C)
unnamed: Q1.1 (B), R12.1, R13.1
VB: C5.2, D1.1 (K), D2.2 (A), D4.1 (K), D5.2 (A), R10.2; also elsewhere on the board

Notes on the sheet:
C: COUPLING
D: SOFT / HARD CLIPPING
SOFT (germanium)
HARD (silicon)
Relay off = Soft, relay on = Hard. HARD_SEL comes from the microcontroller (controller sheet). R13 keeps the relay off (Soft) until the microcontroller starts. +5V comes from the regulator on the Power sheet.

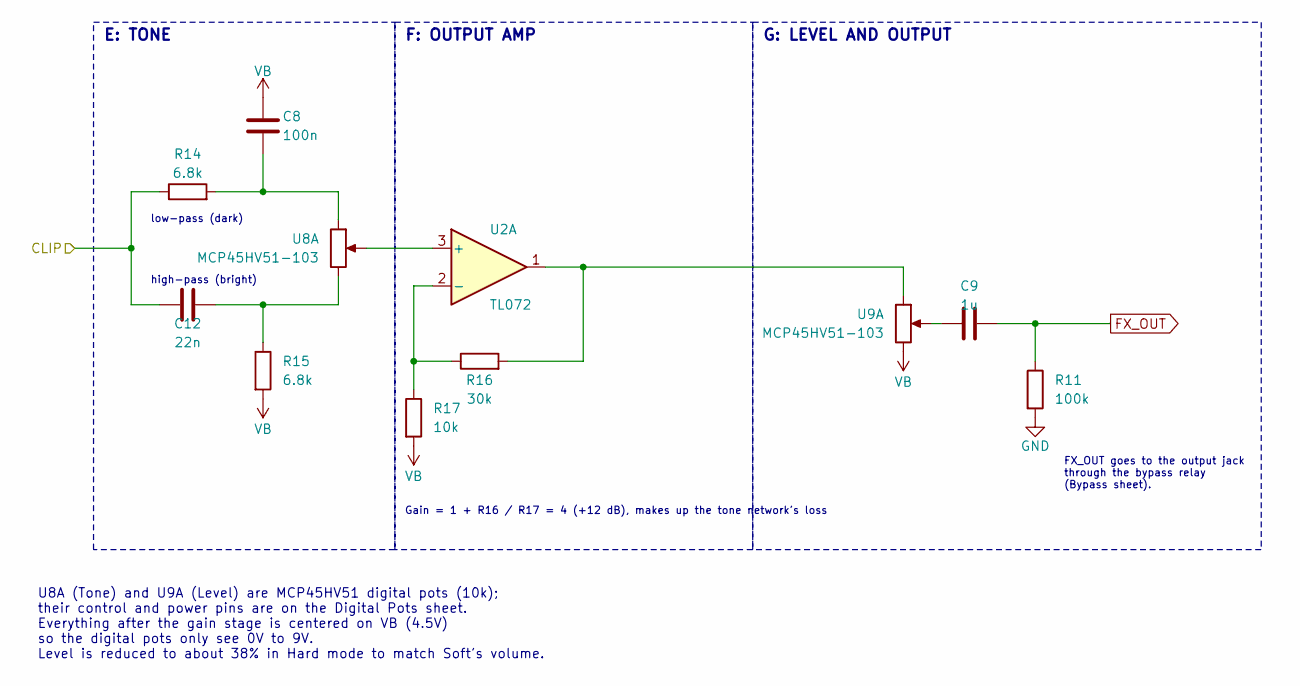
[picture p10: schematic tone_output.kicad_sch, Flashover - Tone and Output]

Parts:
C8: 100n; C_1206_3216Metric
C9: 1u; C_1210_3225Metric
C12: 22n; C_1206_3216Metric
R11: 100k; R_0805_2012Metric
R14, R15: 6.8k; R_0805_2012Metric
R16: 30k; R_0805_2012Metric
R17: 10k; R_0805_2012Metric
U2: TL072; SOIC-8_3.9x4.9mm_P1.27mm
U8, U9: MCP45HV51-103; TSSOP-14_4.4x5mm_P0.65mm

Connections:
/Clipping/CLIP: C12.1, R14.1; also elsewhere on the board
FX_OUT: C9.2, R11.1; also elsewhere on the board
GND: R11.2; also elsewhere on the board
unnamed: C8.2, R14.2, U8.13
unnamed: C9.1, U9.12
unnamed: C12.2, R15.1, U8.11
unnamed: R16.2, U2.1, U9.13
unnamed: U2.3 (+), U8.12
unnamed: R16.1, R17.1, U2.2 (-)
VB: C8.1, R15.2, R17.2, U9.11; also elsewhere on the board

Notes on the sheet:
E: TONE
F: OUTPUT AMP
G: LEVEL AND OUTPUT
low-pass (dark)
high-pass (bright)
FX_OUT goes to the output jack through the bypass relay (Bypass sheet).
Gain = 1 + R16 / R17 = 4 (+12 dB), makes up the tone network's loss
U8A (Tone) and U9A (Level) are MCP45HV51 digital pots (10k); their control and power pins are on the Digital Pots sheet. Everything after the gain stage is centered on VB (4.5V) so the digital pots only see 0V to 9V. Level is reduced to about 38% in Hard mode to match Soft's volume.

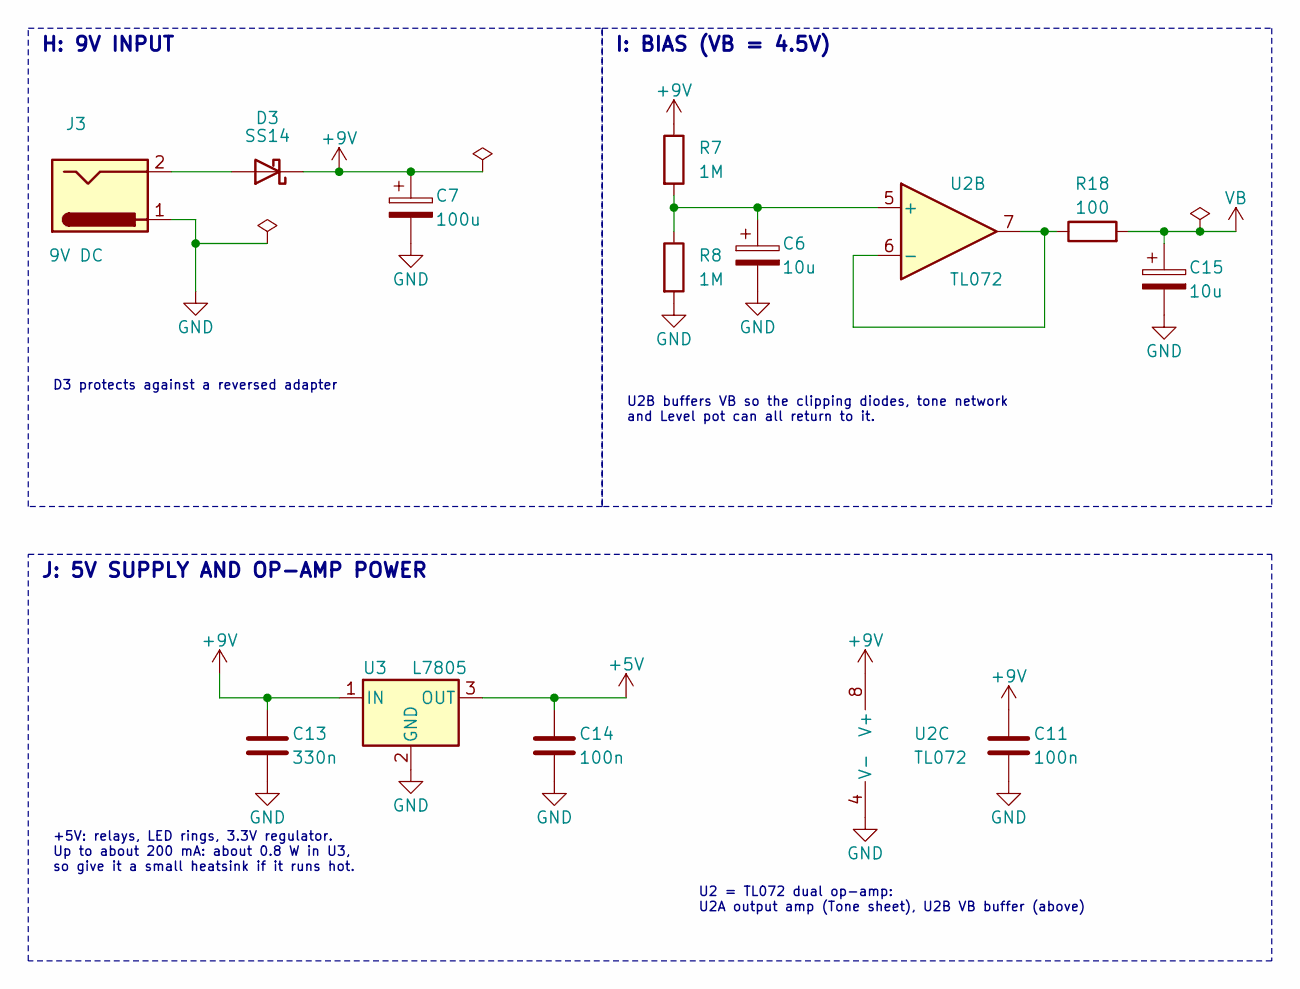
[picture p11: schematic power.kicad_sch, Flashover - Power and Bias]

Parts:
C6, C15: 10u; CP_Elec_5x5.4
C7: 100u; CP_Elec_6.3x5.4
C11, C14: 100n; C_0805_2012Metric
C13: 330n; C_0805_2012Metric
D3: SS14; D_SMA
J3: 9V DC; BarrelJack_CUI_PJ-102AH_Horizontal
R7, R8: 1M; R_0805_2012Metric
R18: 100; R_0805_2012Metric
U2: TL072; SOIC-8_3.9x4.9mm_P1.27mm
U3: L7805; TO-220-3_Horizontal_TabDown

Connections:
+5V: C14.1, U3.3 (OUT); also elsewhere on the board
+9V: C7.1, C11.1, C13.1, D3.1 (K), R7.1, U2.8 (V+), U3.1 (IN); also elsewhere on the board
GND: C6.2, C7.2, C11.2, C13.2, C14.2, C15.2, J3.1, R8.2, U2.4 (V-), U3.2 (GND); also elsewhere on the board
unnamed: D3.2 (A), J3.2
unnamed: C6.1, R7.2, R8.1, U2.5 (+)
unnamed: R18.1, U2.6 (-), U2.7
VB: C15.1, R18.2; also elsewhere on the board

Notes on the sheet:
H: 9V INPUT
I: BIAS (VB = 4.5V)
J: 5V SUPPLY AND OP-AMP POWER
D3 protects against a reversed adapter
U2B buffers VB so the clipping diodes, tone network and Level pot can all return to it.
+5V: relays, LED rings, 3.3V regulator. Up to about 200 mA: about 0.8 W in U3, so give it a small heatsink if it runs hot.
U2 = TL072 dual op-amp: U2A output amp (Tone sheet), U2B VB buffer (above)

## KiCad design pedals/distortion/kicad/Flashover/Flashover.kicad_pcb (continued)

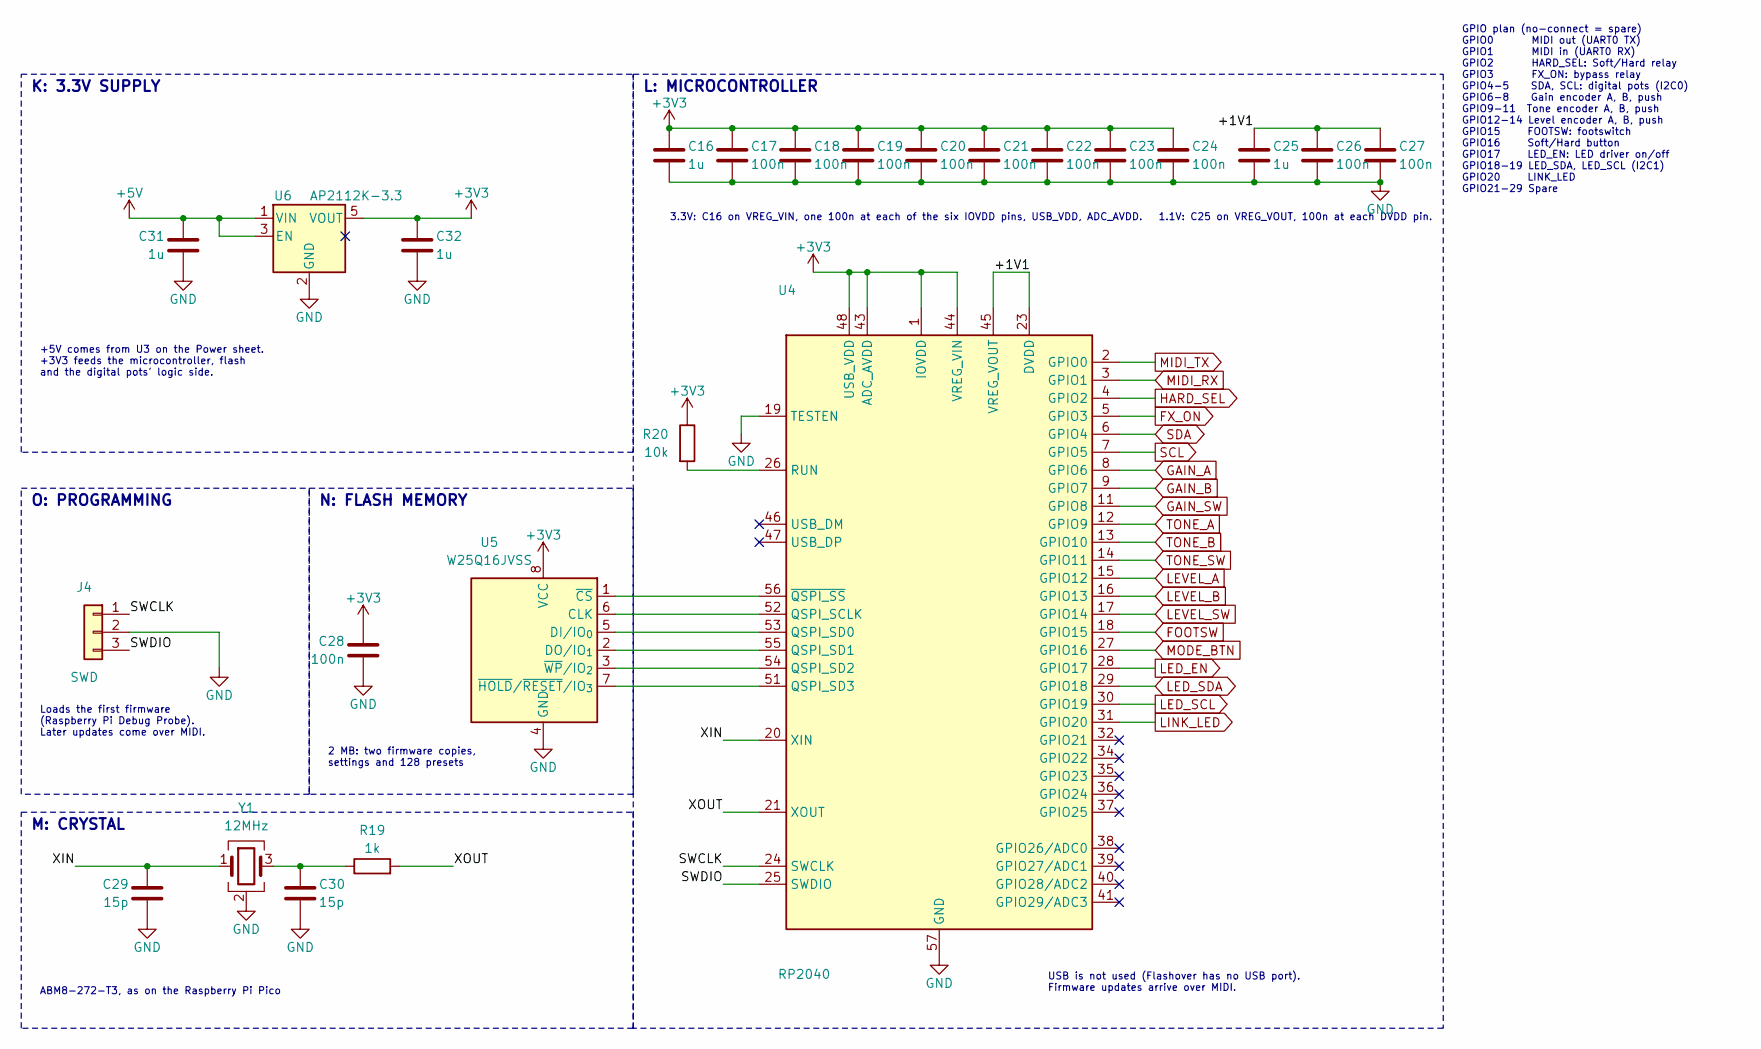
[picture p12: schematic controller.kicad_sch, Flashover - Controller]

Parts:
C16, C25, C31, C32: 1u; C_0805_2012Metric
C17, C18, C19, C20, C21, C22, C23, C24, C26, C27, C28: 100n; C_0805_2012Metric
C29, C30: 15p; C_0805_2012Metric
J4: SWD; JST_SH_SM03B-SRSS-TB_1x03-1MP_P1.00mm_Horizontal
R19: 1k; R_0805_2012Metric
R20: 10k; R_0805_2012Metric
U4: RP2040; QFN-56-1EP_7x7mm_P0.4mm_EP3.2x3.2mm
U5: W25Q16JVSS; SOIC-8_5.3x5.3mm_P1.27mm
U6: AP2112K-3.3; SOT-23-5
Y1: 12MHz; Crystal_SMD_3225-4Pin_3.2x2.5mm

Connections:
+3V3: C16.1, C17.1, C18.1, C19.1, C20.1, C21.1, C22.1, C23.1, C24.1, C28.1, C32.1, R20.1, U4.1 (IOVDD), U4.10 (IOVDD), U4.22 (IOVDD), U4.33 (IOVDD), U4.42 (IOVDD), U4.43 (ADC_AVDD), U4.44 (VREG_VIN), U4.48 (USB_VDD), U4.49 (IOVDD), U5.8 (VCC), U6.5 (VOUT); also elsewhere on the board
+5V: C31.1, U6.1 (VIN), U6.3 (EN); also elsewhere on the board
/Controller/+1V1: C25.1, C26.1, C27.1, U4.23 (DVDD), U4.45 (VREG_VOUT), U4.50 (DVDD)
/Controller/SWCLK: J4.1, U4.24 (SWCLK)
/Controller/SWDIO: J4.3, U4.25 (SWDIO)
/Controller/XIN: C29.1, U4.20 (XIN), Y1.1
/Controller/XOUT: R19.2, U4.21 (XOUT)
FOOTSW: U4.18 (GPIO15); also elsewhere on the board
FX_ON: U4.5 (GPIO3); also elsewhere on the board
GAIN_A: U4.8 (GPIO6); also elsewhere on the board
GAIN_B: U4.9 (GPIO7); also elsewhere on the board
GAIN_SW: U4.11 (GPIO8); also elsewhere on the board
GND: C16.2, C17.2, C18.2, C19.2, C20.2, C21.2, C22.2, C23.2, C24.2, C25.2, C26.2, C27.2, C28.2, C29.2, C30.2, C31.2, C32.2, J4.2, U4.19 (TESTEN), U4.57 (GND), U5.4 (GND), U6.2 (GND), Y1.2 (G), Y1.4 (G); also elsewhere on the board
HARD_SEL: U4.4 (GPIO2); also elsewhere on the board
LED_EN: U4.28 (GPIO17); also elsewhere on the board
LED_SCL: U4.30 (GPIO19); also elsewhere on the board
LED_SDA: U4.29 (GPIO18); also elsewhere on the board
LEVEL_A: U4.15 (GPIO12); also elsewhere on the board
LEVEL_B: U4.16 (GPIO13); also elsewhere on the board
LEVEL_SW: U4.17 (GPIO14); also elsewhere on the board
LINK_LED: U4.31 (GPIO20); also elsewhere on the board
MIDI_RX: U4.3 (GPIO1); also elsewhere on the board
MIDI_TX: U4.2 (GPIO0); also elsewhere on the board
MODE_BTN: U4.27 (GPIO16); also elsewhere on the board
unnamed: C30.1, R19.1, Y1.3
unnamed: U4.52 (QSPI_SCLK), U5.6 (CLK)
unnamed: U4.53 (QSPI_SD0), U5.5 (DI/IO_{0})
unnamed: U4.55 (QSPI_SD1), U5.2 (DO/IO_{1})
unnamed: U4.54 (QSPI_SD2), U5.3 (~WP/IO_{2})
unnamed: U4.51 (QSPI_SD3), U5.7 (~HOLD/~RESET/IO_{3})
unnamed: R20.2, U4.26 (RUN)
unnamed: U4.56 (~QSPI_SS), U5.1 (~CS)
SCL: U4.7 (GPIO5); also elsewhere on the board
SDA: U4.6 (GPIO4); also elsewhere on the board
TONE_A: U4.12 (GPIO9); also elsewhere on the board
TONE_B: U4.13 (GPIO10); also elsewhere on the board
TONE_SW: U4.14 (GPIO11); also elsewhere on the board

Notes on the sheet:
K: 3.3V SUPPLY
L: MICROCONTROLLER
O: PROGRAMMING
N: FLASH MEMORY
M: CRYSTAL
+5V comes from U3 on the Power sheet. +3V3 feeds the microcontroller, flash and the digital pots' logic side.
3.3V: C16 on VREG_VIN, one 100n at each of the six IOVDD pins, USB_VDD, ADC_AVDD. 1.1V: C25 on VREG_VOUT, 100n at each DVDD pin.
GPIO plan (no-connect = spare) GPIO0 MIDI out (UART0 TX) GPIO1 MIDI in (UART0 RX) GPIO2 HARD_SEL: Soft/Hard relay GPIO3 FX_ON: bypass relay GPIO4-5 SDA, SCL: digital pots (I2C0) GPIO6-8 Gain encoder A, B, push GPIO9-11 Tone encoder A, B, push GPIO12-14 Level encoder A, B, push GPIO15 FOOTSW: footsw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
USB is not used (Flashover has no USB port). Firmware updates arrive over MIDI.
2 MB: two firmware copies, settings and 128 presets
ABM8-272-T3, as on the Raspberry Pi Pico
Loads the first firmware (Raspberry Pi Debug Probe). Later updates come over MIDI.


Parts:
R21, R22: 4.7k; R_0805_2012Metric
U7: MCP45HV51-104; TSSOP-14_4.4x5mm_P0.65mm
U8, U9: MCP45HV51-103; TSSOP-14_4.4x5mm_P0.65mm

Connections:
+3V3: R21.1, R22.1, U7.1 (VL), U7.8 (~SHDN), U8.1 (VL), U8.5 (A0), U8.8 (~SHDN), U9.1 (VL), U9.3 (A1), U9.8 (~SHDN); also elsewhere on the board
+9V: U7.14 (V+), U8.14 (V+), U9.14 (V+); also elsewhere on the board
GND: U7.3 (A1), U7.5 (A0), U7.6 (~WLAT), U7.9 (DGND), U7.10 (V-), U8.3 (A1), U8.6 (~WLAT), U8.9 (DGND), U8.10 (V-), U9.5 (A0), U9.6 (~WLAT), U9.9 (DGND), U9.10 (V-); also elsewhere on the board
SCL: R22.2, U7.2 (SCL), U8.2 (SCL), U9.2 (SCL); also elsewhere on the board
SDA: R21.2, U7.4 (SDA), U8.4 (SDA), U9.4 (SDA); also elsewhere on the board

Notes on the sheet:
P: GAIN POT (100k)
I2C address 0x3C (A1=0, A0=0)
Q: TONE POT (10k)
I2C address 0x3D (A1=0, A0=1)
R: LEVEL POT (10k)
I2C address 0x3E (A1=1, A0=0)
S: I2C PULL-UPS
The pot side of each chip (U7A, U8A, U9A) is drawn on the audio sheets where it acts. V+ = 9V and V- = GND, so the pot ends can swing anywhere from 0V to 9V. VL = 3.3V matches the microcontroller's logic. WLAT tied low: a new setting takes effect at once. SHDN tied high: normal operation. At power-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

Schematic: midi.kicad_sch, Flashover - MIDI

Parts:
C41: 100n; C_0805_2012Metric
D43: 1N4148W; D_SOD-123
J5: MIDI In; Jack_3.5mm_CUI_SJ1-3523N_Horizontal
J6: MIDI Out; Jack_3.5mm_CUI_SJ1-3523N_Horizontal
R37: 220; R_0805_2012Metric
R38: 1k; R_0805_2012Metric
R39: 33 0.5W; R_2010_5025Metric
R40: 10; R_0805_2012Metric
U11: H11L1; SMDIP-6_W7.62mm

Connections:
+3V3: C41.1, R38.1, R39.2, U11.6; also elsewhere on the board
GND: C41.2, J6.S, U11.5; also elsewhere on the board
MIDI_RX: R38.2, U11.4; also elsewhere on the board
MIDI_TX: R40.1; also elsewhere on the board
unnamed: D43.2 (A), J5.T, U11.2
unnamed: D43.1 (K), R37.2, U11.1
unnamed: J5.R, R37.1
unnamed: J6.R, R39.1
unnamed: J6.T, R40.2

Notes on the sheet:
AD: MIDI IN
AE: MIDI OUT
Type A wiring: Tip = MIDI pin 5, Ring = MIDI pin 4, Sleeve = shield. The sleeve is left unconnected on the input, as the MIDI spec asks, to avoid ground loops. D43 protects the optocoupler if a reversed (Type B) cable is plugged in. The H11L1 runs from 3.3V and its output idles high, as the UART ex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
3.3V MIDI output, using the values in the MIDI Association's 3.3V update: 33 ohm from +3.3V to pin 4 (Ring) and 10 ohm from the UART to pin 5 (Tip). The sleeve is grounded on the output.
No hardware MIDI thru. The firmware passes on every message it receives and adds its own (merging, per the Linework Control Specification). If the pedal loses power the loop stops here; Switchyard detects the break. MIDI_RX and MIDI_TX go to UART0 on the microcontroller (GPIO1 and GPIO0).

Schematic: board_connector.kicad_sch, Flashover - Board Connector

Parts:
H1, H2: M3; MountingHole_3.2mm_M3
J7: To control board; PinSocket_2x10_P2.54mm_Vertical

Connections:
+3V3: J7.5; also elsewhere on the board
+5V: J7.1, J7.2; also elsewhere on the board
GAIN_A: J7.7; also elsewhere on the board
GAIN_B: J7.8; also elsewhere on the board
GAIN_SW: J7.9; also elsewhere on the board
GND: J7.3, J7.4, J7.6; also elsewhere on the board
LED_EN: J7.19; also elsewhere on the board
LED_SCL: J7.18; also elsewhere on the board
LED_SDA: J7.17; also elsewhere on the board
LEVEL_A: J7.13; also elsewhere on the board
LEVEL_B: J7.14; also elsewhere on the board
LEVEL_SW: J7.15; also elsewhere on the board
LINK_LED: J7.20; also elsewhere on the board
MODE_BTN: J7.16; also elsewhere on the board
TONE_A: J7.10; also elsewhere on the board
TONE_B: J7.11; also elsewhere on the board
TONE_SW: J7.12; also elsewhere on the board

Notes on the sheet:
AI: CONTROL BOARD CONNECTOR
2x10 socket, 2.54 mm. The control board's J8 header plugs in from above. It carries +5V (LED driver), +3V3 (pull-ups), the encoder and button signals, the LED driver bus and the Link LED.
AJ: MOUNTING
M3 holes for the standoffs that hold the control board.


Board: 4 copper layers, 84.0 x 84.0 mm, 95 parts (0 on the bottom side), 72 nets.

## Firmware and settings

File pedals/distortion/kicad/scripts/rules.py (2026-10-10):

"""Flashover design rules, written into a .kicad_pro.

KiCad's Python API rewrites the project file with default rules whenever it saves a board,
so this runs after every scripted save as well as from the schematic generator."""
import json
import sys

CLASSES = [("Power", 0.4, ["+9V", "+5V", "VB", "GND", "Net-(D3-A)"]),
           ("Logic power", 0.3, ["+3V3", "*+1V1"])]
CLEARANCE = 0.15
EDGE = 0.3


def apply(pro):
    ns = pro["net_settings"]
    base = dict(ns["classes"][0])
    # small signal vias (0.45 / 0.2 mm) so the router can escape fine-pitch chips; power keeps 0.6 / 0.3
    base.update(name="Default", clearance=CLEARANCE, track_width=0.2, via_diameter=0.45, via_drill=0.2)
    ns["classes"] = [base] + [dict(base, name=n, track_width=w, priority=i, via_diameter=0.6, via_drill=0.3)
                              for i, (n, w, _) in enumerate(CLASSES)]
    ns["netclass_patterns"] = [{"netclass": n, "pattern": p} for n, _, pats in CLASSES for p in pats]
    rules = pro.setdefault("board", {}).setdefault("design_settings", {}).setdefault("rules", {})
    rules.update(min_clearance=CLEARANCE, min_track_width=0.15, min_via_diameter=0.45,
                 min_through_hole_diameter=0.2, min_copper_edge_clearance=EDGE, min_resolved_spokes=1)
    return pro


def apply_file(fn):
    pro = json.load(open(fn, encoding='utf-8'))
    json.dump(apply(pro), open(fn, 'w', encoding='utf-8', newline='\n'), indent=2)


if __name__ == "__main__":
    for fn in sys.argv[1:]:
        apply_file(fn)

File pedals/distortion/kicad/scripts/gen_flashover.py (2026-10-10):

"""Generate the Flashover KiCad project (hierarchical schematic)."""
import os, json, shutil
from kigen import Sheet, U, UK, mm, px, py, f, font

POT = "GreywireStudio:MCP45HV51"
PA, PW, PB = '13', '12', '11'   # pot unit pins: end A, wiper, end B
from paths import KI
OUT = KI + "Flashover"
os.makedirs(OUT, exist_ok=True)

# =====================================================================
# Sheet 2: Input and gain stage
# =====================================================================
s2 = Sheet("Flashover - Input and Gain", 3, "Input buffer network and the GS1 gain stage, scaled for a 100k digital pot")
s = s2
s.box(8, 40, 58, 112, "A: INPUT")
s.box(60, 40, 112, 112, "B: GAIN STAGE")
s.label('global', 'FX_IN', 22, 63, 180, 'input')
s.wire((22, 63), (32, 63), (35, 63))
s.text("FX_IN comes from the input jack\nthrough the bypass relay\n(Bypass sheet).", 10, 80, size=1.0)
r1 = s.add("R1", "Device:R", "1M", 32, 70)
s.wire((32, 63), r1.p('1'))
s.pwr('GND', 32, 73)
c1 = s.add("C1", "Device:C", "10n", 38, 63, rot=90)
r2 = s.add("R2", "Device:R", "10k", 47, 63, rot=90)
s.wire(c1.p('2'), r2.p('1'))
u1 = s.add("U1", "Amplifier_Operational:LM741", "LM741", 72, 65)
s.wire(r2.p('2'), (55, 63), u1.p('3'))
r3 = s.add("R3", "Device:R", "1M", 55, 56)
s.pwr('VB', 55, 53)
s.wire(r3.p('2'), (55, 63))
c2 = s.add("C2", "Device:C", "1n", 55, 70)
s.wire((55, 63), c2.p('1'))
s.pwr('GND', 55, 73)
s.pwr('+9V', 70, 56)
s.wire((70, 56), u1.p('7'))
s.pwr('GND', 70, 74)
s.wire(u1.p('4'), (70, 74))
s.nc(u1.p('1'))
s.nc(u1.p('5'))
# feedback network below the op-amp
r5 = s.add("R5", "Device:R", "100k", 72, 80, rot=90, fields={'ref': (0, 2, None), 'val': (0, 4, None)})
s.wire(u1.p('2'), (63, 67), (63, 80), r5.p('1'))
s.wire(r5.p('2'), (82, 80), (82, 65))
s.wire(u1.p('6'), (82, 65), (92, 65))
s.label('hier', 'GAIN_OUT', 92, 65, 0, 'output')
r4 = s.add("R4", "Device:R", "330", 63, 86)
s.wire((63, 80), r4.p('1'))
rv1 = s.add("U7", POT, "MCP45HV51-104", 63, 95, unit=1, fields={'ref': (5, -1, 'left'), 'val': (5, 1, 'left')})
s.wire(r4.p('2'), rv1.p(PA))
s.wire(rv1.p(PW), (66, 98), rv1.p(PB))
c3 = s.add("C3", "Device:C", "470n", 63, 104)
s.wire(rv1.p(PB), c3.p('1'))
s.pwr('GND', 63, 107)
# decoupling
c10 = s.add("C10", "Device:C", "100n", 100, 92)
s.pwr('+9V', 100, 89)
s.pwr('GND', 100, 95)
s.text("U1 supply decoupling", 92, 83)
s.text("Gain = 1 + R5 / (R4 + U7A):  about 2x (min) to 216x (max)\n"
       "U7A is the Gain knob: the pot side of an MCP45HV51 digital pot (100k).\n"
       "Its control and power pins (U7B) are on the Digital Pots sheet.", 8, 118)

# =====================================================================
# Sheet 3: Clipping (Soft / Hard)
# =====================================================================
s3 = Sheet("Flashover - Clipping", 4, "Soft (germanium) or Hard (silicon) clipping, selected by relay K1")
s = s3
s.box(14, 36, 54, 66, "C: COUPLING")
s.box(54, 36, 140, 104, "D: SOFT / HARD CLIPPING")
s.label('hier', 'GAIN_OUT', 12, 48, 180, 'input')
c4 = s.add("C4", "Device:C", "1u", 20, 48, rot=90)
s.wire((12, 48), c4.p('1'))
r6 = s.add("R6", "Device:R", "10k", 29, 48, rot=90)
s.wire(c4.p('2'), r6.p('1'))
k1 = s.add("K1", "Relay:G6K-2", "G6K-2F-Y 5VDC", 80, 60, rot=180,
           fields={'ref': (4, -10, 'left'), 'val': (4, -8.5, 'left')})
s.wire(r6.p('2'), (36, 48), (40, 48), (46, 48), (72, 48), (80, 48), k1.p('3'))
s.wire((72, 48), k1.p('6'))
r10 = s.add("R10", "Device:R", "1M", 40, 55)
s.wire((40, 48), r10.p('1'))
s.pwr('VB', 40, 58, rot=180)
c5 = s.add("C5", "Device:C", "1n", 46, 55)
s.wire((46, 48), c5.p('1'))
s.pwr('VB', 46, 58, rot=180)
s.wire((36, 48), (36, 42))
s.label('hier', 'CLIP', 36, 42, 0, 'output')
# unused contacts
s.nc(k1.p('4'))
s.nc(k1.p('7'))
# Soft: germanium pair on the normally-closed contact (relay off = Soft)
L = {'ref': (-2, -1, 'right'), 'val': (-2, 1, 'right')}
Rr = {'ref': (2, -1, 'left'), 'val': (2, 1, 'left')}
s.wire(k1.p('2'), (82, 70), (74, 70))
d1 = s.add("D1", "Device:D", "1N34A", 82, 75, rot=90, fields=Rr)
d2 = s.add("D2", "Device:D", "1N34A", 74, 75, rot=270, fields=Rr)
s.wire((82, 70), d1.p('2'))
s.wire((74, 70), d2.p('1'))
s.wire(d1.p('1'), (82, 80), (78, 80), (74, 80), d2.p('2'))
s.wire((78, 80), (78, 82))
s.pwr('VB', 78, 82, rot=180)
s.text("SOFT\n(germanium)", 74, 89)
# Hard: silicon pair on the normally-open contact of the second pole
s.wire(k1.p('5'), (70, 70), (60, 70))
d4 = s.add("D4", "Device:D", "1N4148W", 70, 75, rot=90, fields=L)
d5 = s.add("D5", "Device:D", "1N4148W", 60, 75, rot=270, fields=L)
s.wire((70, 70), d4.p('2'))
s.wire((60, 70), d5.p('1'))
s.wire(d4.p('1'), (70, 80), (65, 80), (60, 80), d5.p('2'))
s.wire((65, 80), (65, 82))
s.pwr('VB', 65, 82, rot=180)
s.text("HARD\n(silicon)", 61, 89)
# coil driver
d6 = s.add("D6", "Device:D", "1N4148W", 92, 60, rot=90, fields=Rr)
q1 = s.add("Q1", "Transistor_BJT:MMBT3904", "MMBT3904", 108, 74, mirror='y', fields={'ref': (-6, -1, 'right'), 'val': (-6, 1, 'right')})
s.wire(k1.p('8'), (92, 54), (106, 54), q1.p('3'))
s.wire((92, 54), d6.p('2'))
s.wire(d6.p('1'), (92, 66), k1.p('1'))
s.wire(k1.p('1'), (88, 69))
s.pwr('+5V', 88, 69, rot=180)
s.pwr('GND', 106, 78)
r12 = s.add("R12", "Device:R", "4.7k", 118, 74, rot=90)
s.wire(q1.p('1'), (113, 74), r12.p('1'))
r13 = s.add("R13", "Device:R", "100k", 113, 79)
s.wire((113, 74), r13.p('1'))
s.pwr('GND', 113, 82)
s.wire(r12.p('2'), (124, 74))
s.label('global', 'HARD_SEL', 124, 74, 0, 'input')
s.text("Relay off = Soft, relay on = Hard.\n"
       "HARD_SEL comes from the microcontroller (controller sheet).\n"
       "R13 keeps the relay off (Soft) until the microcontroller starts.\n"
       "+5V comes from the regulator on the Power sheet.", 8, 112)
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

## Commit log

2026-10-04 Add empty GS1 KiCad project for distortion pedal
    [GS1.kicad_pcb, GS1.kicad_sch]
2026-10-04 Add bias voltage section to GS1 schematic; ignore KiCad local history
    [GS1.kicad_sch]
2026-10-04 Add input section to GS1 schematic
    [GS1.kicad_sch]
2026-10-04 Add op-amp gain stage to GS1 schematic
    [GS1.kicad_sch]
2026-10-04 Complete GS1 schematic with output and clipping section
    [GS1.kicad_sch]
2026-10-05 Add power input, true-bypass footswitch and LED to GS1
    Adds a shared GreywireStudio symbol library with a 3PDT footswitch symbol.
    [GS1.kicad_sch]
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2026-10-05 Add section headings and dividers to GS1 schematic
    [GS1.kicad_sch]
2026-10-05 Rename GS1 schematic title; remove stray divider segment
    [GS1.kicad_sch]
2026-10-05 Add product concept doc with connectivity analysis and build notes
    General Concept.docx describes the networked pedal idea and now ends
    with an analysis of Wi-Fi vs Bluetooth connectivity, other options,
    and rough costs. general-instructions-1.txt holds the GS1 build and
    KiCad walkthrough notes.
2026-10-05 Add certification and USB-to-phone sections to concept doc
    Covers which certifications apply to analog pedals without wireless,
    and the cost and trade-offs of connecting the pedal to the internet
    through the player's phone over USB-C instead of Wi-Fi or Bluetooth.
2026-10-06 Add Fully Integrated Mobile Device section to concept doc
    Explores moving the pedal's processing onto the phone: why the pedal
    still needs a USB chip, three ways to split the work, how the phone
    changes knob settings, USB audio/MIDI protocols, latency, fail-safe
    bypass, power, and costs.
2026-10-06 Rework mobile device section around hybrid analog/digital design
    Latency-sensitive effects (drive, compression, filters) stay as analog
    circuits in the pedal; time-based effects run in the phone app on a
    wet-only path so the dry signal is never delayed. Updates the options,
    effect placement, signal flow, control protocol, failure behavior,
    power and cost estimates to match.
2026-10-06 Clarify that band-level monitoring is done by a separate person
    The person measuring the band's mix uses their own phone out in the
    room, not the musician's phone on the pedalboard. Corrects the
    connectivity, USB and mobile device sections accordingly and adds a
    Band-Level Monitoring section describing how adjustments reach each
    pedal.
2026-10-07 Add Switchyard and Flashover product documents
    Names the Linework series, the Switchyard control pedal and the
    Flashover distortion/overdrive pedal, with a basic product document for
    each. Updates the READMEs with the names and a new controller folder,
    and ignores Office lock files.
2026-10-07 Update Flashover doc: Soft/Hard clipping, MIDI chaining, endless knobs
    Adds a Soft (germanium) / Hard (silicon) clipping toggle, explains how
    one Switchyard MIDI output controls several pedals via channels and
    MIDI thru, and settles on endless knobs with LED rings. Updates
    hardware, costs, next steps and open questions to match.
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2026-10-08 Add Flashover KiCad schematic (hierarchical, 5 pages)
    Root sheet plus Power and Bias, Input and Gain, Clipping, and Tone and
    Output sheets, matching the LTspice model. Adds the relay driver, 78L05
    +5V supply, and R18/C15 VB isolation. ERC clean apart from the HARD_SEL
    label awaiting the controller sheet. Adds a VB power symbol to the
    shared library.
    [Flashover.kicad_sch, clipping.kicad_sch, input_gain.kicad_sch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]
2026-10-08 Add Flashover controller and digital pot sheets
    Controller sheet: RP2040 with 3.3V regulator, 2 MB QSPI flash, 12 MHz
    crystal and SWD header, plus a GPIO plan for the sheets still to come.
    Digital Pots sheet: control side of three MCP45HV51 I2C pots with
    pull-ups. RV1-RV3 on the audio sheets become the pot units of U7-U9
    (new two-unit MCP45HV51 symbol in the shared library). ERC clean.
    [Flashover.kicad_sch, clipping.kicad_sch, controller.kicad_sch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]
2026-10-09 Add Flashover controls and LED ring sheets
    Controls sheet: three PEC11R encoders with push switches (pull-ups and
    RC filtering) and the Soft/Hard button. LED Rings sheet: IS31FL3236A
    driving three 11-LED rings plus Soft, Hard and On LEDs, on its own I2C
    bus. Controller sheet wires the new GPIOs; the 5V regulator becomes an
    L7805 for the LED load. ERC clean.
    [Flashover.kicad_sch, clipping.kicad_sch, controller.kicad_sch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]
2026-10-09 Add Flashover MIDI sheet
    MIDI in (H11L1 optocoupler, 220 ohm, reverse-protection diode, sleeve
    unconnected) and MIDI out (3.3V drive: 33 ohm to pin 4, 10 ohm to pin 5)
    on 3.5 mm TRS Type A jacks, wired to UART0. Root sheet re-spaced for
    nine sheets. ERC clean.
    [Flashover.kicad_sch, clipping.kicad_sch, controller.kicad_sch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]
2026-10-09 Add Flashover bypass sheet; complete schematic
    Bypass sheet: fail-safe G6K-2 relay bypass (NC contacts join the jacks
    when unpowered), input/output jacks moved here from the audio sheets
    (now FX_IN/FX_OUT), relay driver on FX_ON, soft-touch footswitch and
    Link LED. Relay coils on K1 and K2 now take +5V on pin 1 (marked +).
    Root sheet laid out in four columns. ERC clean.
    [Flashover.kicad_sch, bypass.kicad_sch, controller.kicad_sch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]
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2026-10-09 Apply datasheet checks to Flashover
    R33 = 15k (about 5 mA per LED, from the IS31FL3236A current formula).
    R39 marked 33 ohm 0.5W per MIDI CA-033. R4 390 -> 330 because the
    MCP45HV51 wiper resistance is about 150 ohms at 9V (below its 10V
    specified range); sim model Rw updated to match. Pot symbol description
    corrected to 8-bit. Product document records the check results.
    [Flashover.kicad_sch, bypass.kicad_sch, clipping.kicad_sch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]
2026-10-09 Assign Flashover footprints
    Surface-mount for assembly; through-hole for jacks, encoders, panel LEDs,
    the Soft/Hard button, the TO-220 regulator and the germanium diodes.
    Q1/Q2 use the MMBT3904 symbol, 1N4148 -> 1N4148W, 1N5817 -> SS14.
    [Flashover.kicad_sch, bypass.kicad_sch, clipping.kicad_sch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]
2026-10-09 Split Flashover into main and control boards; place parts
    Main board (Flashover): audio, controller, pots, MIDI, bypass and the five
    top-mounted jacks. Control board (Flashover_Controls): encoders, LED rings,
    LED driver, Soft/Hard button and panel LEDs. J7/J8 2x10 board connector,
    M3 mounting holes, regulator laid flat. Placement only, not yet routed.
    [Flashover.kicad_pcb, Flashover.kicad_sch, Flashover_Controls.kicad_pcb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]
2026-10-09 Route Flashover boards (partial); add status note
    Both boards now 4-layer with inner ground (and +5V) planes, JLCPCB-style
    rules and net classes, ground/+5V via fan-out and autorouted signals.
    Control board: 7 connections open. Main board: 50 open; to be finished
    by hand. See pedals/distortion/kicad/FLASHOVER_STATUS.md.
    [Flashover.kicad_pcb, Flashover_Controls.kicad_pcb]
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2026-10-10 Hand-route two Flashover control board connections
    U10 +5V (pad 41) via to the +5V plane, and HARD to D41 on B.Cu.
    5 connections left. drc.sh now refills zones before checking.
    [Flashover_Controls.kicad_pcb]
2026-10-11 Finish routing the Flashover control board by hand
    All connections routed (L7, L9, L10, G1, LED_SDA by hand) and the
    autorouter's leftover track stubs removed. DRC: 0 unconnected, 0 errors,
    schematic parity clean; only silkscreen warnings remain.
    [Flashover_Controls.kicad_pcb]
2026-10-11 Fit Flashover to the 1590BB and part datasheets
    - Correct PEC11R encoder footprint (legs 13.2 mm apart) in a new
    GreywireStudio footprint library; swap it onto the control board and
    bend three tracks around the wider legs
    - Move MIDI jacks to the side walls, spread the top jacks out and put
    their fronts against the wall; re-autoroute the main board
    - gen_pcb.py rebuilds the control board only with --controls
    - Add fit check, board heights and drilling guide to the status note;
    update the product document
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2026-10-13 Finish routing the Flashover main board (0 open, 0 errors)
    Reroute GAIN/TONE on U4's crowded left side so pins 10 and 13 can escape,
    reach U9 pin 1 through a via (moving one SCL segment), and add a ground
    stitching via for a cut-off patch of fill. Both boards are now fully routed
    and match their schematics.
2026-10-14 Use a side-entry footswitch connector on the Flashover main board
    The upright JST PH header (SW5) sat under the control board with only
    5 mm above it for the wires. The side-entry S2B-PH-K-S takes the plug
    from the front edge, so it can be connected after stacking. It moves
    2.75 mm toward the edge, and the FOOTSW track is shortened to match.
    Still 0 unconnected, 0 errors, schematic parity clean.
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2026-10-16 Add optional clipping test diodes to the Flashover Tayda order
    Adds 1N60, BAT46, 1N4001, 1N5817 and red LED pairs for swapping into
    the Soft/Hard clipping positions, with a note on fitting them and
    matching volume before comparing.
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2026-10-18 Start Switchyard Audio: plan and stage 1 breadboard
    Switchyard Audio is a second Switchyard version that carries the guitar
    signal and adds digital effects after the analog Linework pedals. Effects
    run on a processor in the pedal, replacing the General Concept's
    phone-based plan. Stage 1 is a Daisy Seed delay with a TL072 buffer and
    mixer and a fail-safe bypass relay.
2026-10-18 Correct the Switchyard Audio parts estimate to $50-104
    The shared-with-Switchyard line counted the controller and enclosure
    twice. Also explain why the range is wide.
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2026-10-19 Add the next four pedals and their name search
    Tap Changer (boost), Three Phase (phaser), Rolling Blackout (tremolo)
    and Double Circuit (chorus) join the pedal table as ideas. The
    trademark and existing-pedal search behind the names, including the
    rejected ones (Brownout is a live pedal mark), is in IP_RESEARCH.md.
    The README also links the website.
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2026-11-04 Add the Linework Web MIDI test tool and a simulated-loop bridge
    tools/linework-test/: a web page that stands in for the phone app
    (Chrome/Edge Web MIDI): Switchyard info, loop status, position and
    Jump, scan and pedal list, presets through the loop, setlist upload
    from a short text format, other-brands messages, raw messages and a
    decoded log. lw.js holds the protocol client (sequence numbers, 1 s
    timeout, three tries). sim-server.js serves the page and connects it
    to firmware/test/bridge.c, which runs the real core with three
    stand-in pedals, so the tool works without hardware. test/run.js
    passes 27 checks against the bridge; the firmware simulation (now
    sharing world.h with the bridge) sti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
2026-11-05 Add the Linework loader and firmware updates over MIDI
    - lw_fw: flash layout (loader 32 KB, firmware at 0x8000, download area,
    update record, settings), receiving an update, install at power-up with
    CRC checks, repair, recovery mode, 7-bit packing of data blocks.
    - pedal.c handles Firmware: begin/data/finish (30-32): erase in gaps, busy
    and checksum acks, block-number acks, restart, announce after install;
    Flashover and Tap Changer stay bypassed during an update.
    - pico: lw_update, loader.c, linework.cmake (firmware linked at 32 KB,
    per-pedal loader, merged _full.uf2), tools/uf2_merge.py.
    - test/fw_sim.c: 39 checks incl. power cuts, damage and recovery.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
